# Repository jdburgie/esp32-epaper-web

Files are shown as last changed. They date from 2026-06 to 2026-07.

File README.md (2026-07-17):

# ESP32 E-Paper Web Display

Drive a 2.13" e-paper panel from an ESP32 (or an ESP8266/ESP-12E — see below)
and change the text from any browser on your network. No app, no cloud — just
type and submit.

## Enclosure & battery

A 3D-printable case and an 18650 + load-sharing-charger power design live in
[`enclosure/`](enclosure/) — parametric OpenSCAD source plus ready-to-print STLs,
a power BOM/wiring guide, and print/assembly notes.

## Hardware

- **MCU:** NodeMCU ESP32 DevKit V1 (30-pin) on a dual breakout/expansion shield
- **Driver board:** Inland e-paper driver board (SPI, 8-pin header, 5V/3.3V switch)
- **Panel:** FPC-A002 ribbon, 2.13" 250x122 b/w, SSD1680 controller

## Wiring

Driver board switch **P2 set to 3.3VIN**. All signal lines on the ESP32's
right-side header.

| Driver board | ESP32 pin | GPIO |
|---|---|---|
| SDI (MOSI) | D23 | 23 |
| SCLK (CLK) | D18 | 18 |
| CS | D5 | 5 |
| D/C | D19 | 19 |
| RES | RX2 | 16 |
| BUSY | D4 | 4 |
| VCC | 3V3 | — |
| GND | GND | — |

> Keep the board switch on **3.3VIN**. The logic lines are 3.3V — feeding the
> board 5V while driving 3.3V logic is the usual way these get fried.

## Libraries (Arduino IDE Library Manager)

- GxEPD2 (Jean-Marc Zingg)
- Adafruit GFX (dependency of GxEPD2)
- ESPAsyncWebServer (ESP32Async / me-no-dev)
- AsyncTCP (ESP32) — use **ESPAsyncTCP** instead if building for ESP8266 (see
  "ESP8266 (ESP-12E) port" below)

## Setup

**1. Wi-Fi credentials.** Create `secrets.h` next to the sketch (it's gitignored,
so it never gets committed and won't be in a fresh clone):

```cpp
#pragma once
#define SECRET_SSID "your-wifi-name"
#define SECRET_PASS "your-wifi-password"
#define OWM_API_KEY "your-openweathermap-key"   // for weather mode (openweathermap.org/api)

// Optional static IP (comment out USE_STATIC_IP for DHCP). Useful when the
// router has no DHCP reservation option and the station push needs a fixed
// target. Pick an address BELOW the router's DHCP pool to avoid collisions.
#define USE_STATIC_IP
#define STATIC_IP      192,168,12,50
#define STATIC_GATEWAY 192,168,12,1
#define STATIC_SUBNET  255,255,255,0
#define STATIC_DNS1    192,168,12,1
#define STATIC_DNS2    8,8,8,8
```

The sketch `#include`s this file and reads `SECRET_SSID` / `SECRET_PASS` /
`OWM_API_KEY` — you do **not** edit credentials in the `.ino` anymore. A free
OpenWeatherMap key works; if you don't need weather, any non-empty string is fine.

**2. Build & flash.** Either toolchain works:

- **PlatformIO** (config is in `platformio.ini`):
  ```
  pio run -t upload                       # build + flash
  pio device monitor -p COM3 -b 115200    # watch serial
  ```
  Set `upload_port` / `monitor_port` in `platformio.ini` to your board's COM port
  (it won't necessarily be COM3). Libraries resolve automatically.
- **Arduino IDE:** open `esp32-epaper-web.ino`, install the libraries listed above,
  select your ESP32 board + port, and upload.

**Over-the-air (OTA) updates.** After the first USB flash, the device runs
`ArduinoOTA` (hostname `epaper`, port 3232), so you can flash over Wi-Fi:
```
pio run -e esp32dev_ota -t upload        # uploads to upload_port (device IP) in platformio.ini
```
The partition scheme is `min_spiffs.csv` (two ~1.9 MB app slots) — OTA needs two
app partitions, so a USB flash with this scheme is required once before OTA works.
For a password, add `#define OTA_PASSWORD "…"` to `secrets.h` and set
`upload_flags = --auth=…` in the `esp32dev_ota` env.

**3. Use it.** Open the serial monitor at **115200** — it prints the device IP once
Wi-Fi connects. Browse to that IP. The current IP is also shown in the bottom-left
of the panel at all times.

**If Wi-Fi doesn't connect** (wrong password, network out of range, moved to a
new house), the device doesn't hang or go dark. After ~20s it starts a recovery
**access point** — the panel itself displays the AP name and its IP
(`192.168.4.1`). Connect a phone/laptop to that AP, browse to the IP, and use the
**Wi-Fi card** on the page to enter new credentials; the device saves them and
reboots to try again. This also means you can change Wi-Fi networks later without
re-flashing — the Wi-Fi card is always on the page, not just during recovery.

## Display modes

The control page (themed in the **Three Oak Woods** brand — palette, Nunito, and
the acorn badge served from `logo.h` at `/logo.svg`) offers these modes:

- **Clock** *(default view)* — NTP-synced date and time, redrawn every minute.
  Timezone is set by `TZ_INFO` in the sketch (default Mountain Time, auto DST).
- **Text** — type a message (multi-line supported) and hit **Update Display**.
- **Weather** — enter a US **ZIP code** and hit **Show Weather**. The panel shows
  a drawn weather icon, the **city**, a large **temperature**, the **condition**,
  and a **feels-like / humidity / wind** line. It **auto-refreshes every 5 min**.
- **Backyard Station** — live data pushed from a local **Ambient Weather** console
  (see below). Shows outdoor temp, humidity, wind + direction, gust, rain, and
  pressure, and **redraws on every push** while this mode is active. While waiting
  for the first push it shows a live counter, and **falls back to weather after
  ~90 s** so the panel never looks hung if the console isn't pushing yet.

The page also has a **Clean (de-ghost)** button that flashes the panel black↔white
to scrub e-paper ghosting; the same scrub runs automatically every 6 hours.

**Persistence:** the last view (and Wi-Fi credentials, if set via the recovery
AP) is saved to flash — NVS/`Preferences` on ESP32, a small LittleFS JSON file
on ESP8266 (same `prefs.getString/putString/...` call sites either way) — so
after a power loss the panel restores itself: a remembered ZIP boots straight
back to that weather view; otherwise it boots to the clock.

**Controls & extras:**
- **Physical button** (GPIO27 → GND) cycles Clock → Text → Weather → Station. Also
  on the page: **Next screen** and an **Auto-cycle** toggle.
- **Auto-cycle** advances the screen on a timer (~12 s), but **dwells longer (~30 s)
  on the text screen when it has notes**.
- **Text scrolling:** messages taller than 4 lines page through a 4-line window
  (with a `start/total` indicator).
- **Battery indicator:** an 18650 sensed on GPIO34 (via a 2:1 divider) shows a
  battery % in the top-right of every screen — auto-hidden when no cell is wired.
  See [`enclosure/`](enclosure/) for the battery + charger build.

Weather comes from **[OpenWeatherMap](https://openweathermap.org/api)** (current-
weather endpoint, `units=imperial`). Put a free API key in `secrets.h` as
`OWM_API_KEY`. The JSON response is parsed with ArduinoJson; the fetch uses HTTPS
with certificate validation disabled (fine for a home device). The weather icons
are drawn as 1-bit GFX primitives keyed off the OWM icon code (`01d`, `10n`, …) —
no bitmap assets needed.

> **Architecture note:** web handlers don't draw or fetch directly — they queue a
> `Pending` action that `loop()` executes. This keeps blocking SPI/TLS work off the
> AsyncTCP task and prevents two tasks touching the display at once.

### Connecting an Ambient Weather console (local push)

The ESP32 listens at **`/data/report/`** and ingests the console's "Customized"
upload — no cloud, no API key, your real backyard sensors every minute. In the
console's web UI (the *Customized* section):

| Field | Value |
|---|---|
| Customized | **Enable** |
| Protocol Type Same As | **AmbientWeather** |
| Server IP / Hostname | the **ESP32's IP** (give it a static IP / DHCP reservation so it stays put) |
| Path | `/data/report/` |
| Port | `80` |
| Upload Interval | `60` seconds |

The firmware parses `tempf`, `humidity`, `windspeedmph`, `windgustmph`, `winddir`,
`dailyrainin`, and `baromrelin` and replies `200 OK`. Your existing
AmbientWeather.net cloud upload is independent and keeps working. Tap **Show
Station** on the page to put the live feed on the panel.

> **AMBWeatherPro quirk:** this console joins its parameters onto the URL with
> `&` instead of `?` (`/data/report/&tempf=…`), so there's no query delimiter and
> a normal server parses nothing. The handler works around it by parsing the raw
> URL tail when no `?` is present — so no special path config is needed on the
> console; just set `Server` to the ESP's IP.

## ESP8266 (ESP-12E) port

The whole project also runs on an ESP8266 (e.g. a NodeMCU-style dev board with
an ESP-12E module) via the `esp12e` PlatformIO environment — same firmware,
same features (weather, station push, PWA, OTA, AP-mode recovery), split from
the ESP32 code by `#if defined(ESP32) / #elif defined(ESP8266)` throughout.

```
pio run -e esp12e -t upload           # first flash, over USB
pio run -e esp12e_ota -t upload       # later updates, over Wi-Fi (after the first USB flash)
```

**Wiring (NodeMCU D-pin → GPIO).** Hardware SPI is fixed (SCK/MOSI below) and
used automatically — don't wire anything to D6. **D8/GPIO15 is intentionally
unused**: it must read LOW at boot, and an e-paper driver board's CS-idle
pull-up on that line can prevent the ESP8266 from booting at all.

| Driver board | NodeMCU pin | GPIO | Why this pin |
|---|---|---|---|
| SDI (MOSI) | D7 | 13 | fixed HW SPI |
| SCLK (CLK) | D5 | 14 | fixed HW SPI |
| CS | D3 | 0 | output only — safe on a boot-strap pin |
| D/C | D4 | 2 | output only (also drives the onboard LED — cosmetic) |
| RES | D0 | 16 | no boot-strap meaning either way |
| BUSY | D2 | 4 | **input** from the display — needs a pin with no boot meaning |
| Button | D1 | 5 | input w/ pullup — same reasoning as BUSY |
| Battery | A0 | — | the only ADC pin |
| VCC / GND | 3V3 / GND | — | |

**Battery sense needs empirical calibration.** ESP8266 has one 0–1V ADC; a
NodeMCU board's onboard divider ratio varies by vendor/clone, and this project
adds its **own** 100k/100k divider on top (same physical design as the ESP32
board, feeding A0 at roughly half the cell voltage — safe under any onboard
divider variant). The combined ratio isn't knowable in advance: connect a
charged cell through the divider, compare a multimeter reading to
`analogRead(A0)` in `/status.json`'s `battRawMv`, and set
`BATT_ESP8266_FULLSCALE_V` in the sketch to `(multimeter volts) / (raw/1023.0)`.

**Libraries differ from the ESP32 build:** `ESPAsyncTCP` instead of `AsyncTCP`,
`LittleFS` instead of `Preferences`, `ESP8266WiFi`/`ESP8266HTTPClient` instead
of `WiFi`/`HTTPClient` — all handled by the `esp12e` env's `lib_deps` and the
sketch's `#ifdef`s; nothing to configure by hand.

**PROGMEM matters here.** The embedded web app, logo, and PWA icon are ~14 KB +
12 KB + 23 KB constant blobs. ESP8266 only has ~80 KB of RAM total, and without
`PROGMEM` (keeping them in flash instead of copying to RAM) the firmware simply
won't link. If you regenerate `webapp.h` after editing the web app, keep the
`PROGMEM` keyword — see `webapp/README.md`.

**Static IP: this board is now the deployed device.** `secrets.h`'s
`USE_STATIC_IP` block used to be guarded to `#if defined(ESP32)` specifically so
an ESP8266 build could never collide with the ESP32 unit's static `.50`. That
guard was removed once the ESP32 unit was retired — **this ESP8266/ESP-12E
board now holds `.50`** (see JOURNAL.md). If you ever bring the old ESP32 board
back online while building from this same `secrets.h`, it will *also* try to
claim `.50` and collide with this one — give it a different address (or a
different `secrets.h`) first.

> **Verified so far:** boot, Wi-Fi connect, the recovery AP fallback (forced by
> pointing it at a nonexistent network), the web server/PWA/persistence (all
> stable over USB and OTA flashes) — all on a board with **no e-paper panel
> physically attached yet**. The wiring table above is the intended pin map,
> not yet confirmed against a real panel; the pin choices *do* specifically
> avoid the known ESP8266 boot-strap traps (see the "why this pin" column), but
> give the display module itself a first test before trusting it blind.

## Panel / constructor notes

`FPC-A002` is the *cable* part number, not the controller, and a few revisions
have shipped on that same ribbon. The sketch uses `GxEPD2_213_BN` (SSD1680),
the most common match. If the screen comes up blank or garbled, swap that one
constructor line and re-flash, in this order:

1. `GxEPD2_213_BN`  (default — SSD1680)
2. `GxEPD2_213_B74` (SSD1680, newer revision)
3. `GxEPD2_213_B73` (SSD1675-based)
4. `GxEPD2_213_B72` (SSD1675-based)

The canonical list of every constructor lives in
**File → Examples → GxEPD2 → GxEPD2_Example**.

## Known tradeoffs

- **No deep sleep.** A web server needs the chip awake and on Wi-Fi, so this
  trades microamp sleep current for being interactive. The *panel* still
  hibernates between updates, so burn-in protection is intact.
- **Full-window refresh** every update (the black/white flash). Safe default,
  prevents ghosting. Partial updates are possible later for snappier redraws.
- **No auth or input sanitizing.** Fine on a trusted home network; don't expose
  it to the internet as-is. HTML special characters (`<`, `&`) render literally
  on the panel but can break the web page's "currently showing" line.

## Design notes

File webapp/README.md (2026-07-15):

# Web app (PWA)

A web app that controls the e-paper display from any phone or laptop — a richer
alternative to the minimal page the device serves itself. It talks to the
device's HTTP API and polls `/status.json` for live state (mode, battery,
weather, station). It's a **PWA**: add it to your home screen and it runs
full-screen/standalone with the Three Oak Woods icon.

## Install (add to home screen)
Open the app on the device (`http://192.168.12.50/app`), then:
- **Android (Chrome):** ⋮ menu → **Add to Home screen** (or the **Install app**
  button if it appears).
- **iOS (Safari):** Share → **Add to Home Screen**.

It installs with the badge icon and opens chrome-less, talking to the device
over your LAN.

> **Why no offline / no auto-install prompt:** service workers (offline caching
> and the one-tap install prompt) require a **secure context** — HTTPS or
> localhost. The device serves plain **HTTP**, so the service worker doesn't
> register there (the app still installs to the home screen and works; it just
> isn't cached offline). Hosting the app on HTTPS *would* enable offline, but
> then the browser blocks it from reading the HTTP device (mixed content). Since
> live device data is the whole point, **HTTP-from-the-device is the right call**
> here. The service worker is included and self-activates **if** you ever serve
> the app from a secure origin.

## Run it
**Easiest — the device serves it.** The firmware bundles this app and serves it at
**`/app`**, and the device's control page has an **"Open the web app ↗"** link.
Just browse to the device (e.g. `http://192.168.12.50/`) and click it — no
hosting, and it auto-targets the device it's served from (same origin, no CORS).

**Standalone** — you can also open [`index.html`](index.html) directly (double-click,
`python -m http.server`, or GitHub Pages), then enter the device address and hit
**Connect** (saved in `localStorage`). Cross-origin reads work because the firmware
sends `Access-Control-Allow-Origin: *`.

> **Regenerating the bundle:** the device serves `webapp.h` (auto-generated from
> `index.html`). After editing the SPA, regenerate it from the repo root:
> ```
> { printf '#pragma once\nconst char WEBAPP_HTML[] PROGMEM = R"WEBAPP(\n'; cat webapp/index.html; printf '\n)WEBAPP";\n'; } > webapp.h
> ```
> (prepend the two `// Auto-generated` comment lines if you like), then reflash.
> **Keep the `PROGMEM` keyword** — this ~14KB blob overflows the ESP8266 port's
> RAM without it (harmless/no-op on ESP32). The device reads it via `send_P`,
> which is PROGMEM-aware.

## What it does
- **Live status** every 5 s from `/status.json`: current screen, battery %/volts,
  auto-cycle state.
- **Weather view:** OpenWeatherMap conditions — emoji icon, big temp, city,
  description, and feels-like / humidity / wind.
- **Backyard station view:** live console data — temp, humidity, wind + compass
  direction, gust, rain today, and pressure.
- **Controls** (call the device's existing endpoints):
  - Screens: Clock, Station, Weather (with ZIP), Next, Auto-cycle toggle.
  - Text: multi-line note → Update display.
  - Clear, Clean (de-ghost).

## Why CORS
The app is served from a *different origin* than the device (a file or a host,
not the ESP itself), so the browser blocks reading the device's responses unless
the device sends `Access-Control-Allow-Origin`. The branch firmware adds that
header globally; the action endpoints are simple GETs (no preflight needed).

## Notes
- All control endpoints are plain GET and the app fires them with
  `redirect:'manual'` so it doesn't drag down the device's HTML on every tap.
- The device logo is loaded live from `http://<device>/logo.svg`.
- No build step, no dependencies — one HTML file (Nunito is loaded from Google
  Fonts; it falls back to a system sans if offline).

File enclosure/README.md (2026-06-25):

# Enclosure + battery — ESP32 e-paper weather display

A two-part 3D-printed case that houses the ESP32, the 2.13" e-paper module, an
18650 cell, and a **load-sharing** charger so the unit runs on battery and
recharges over USB *while still running*.

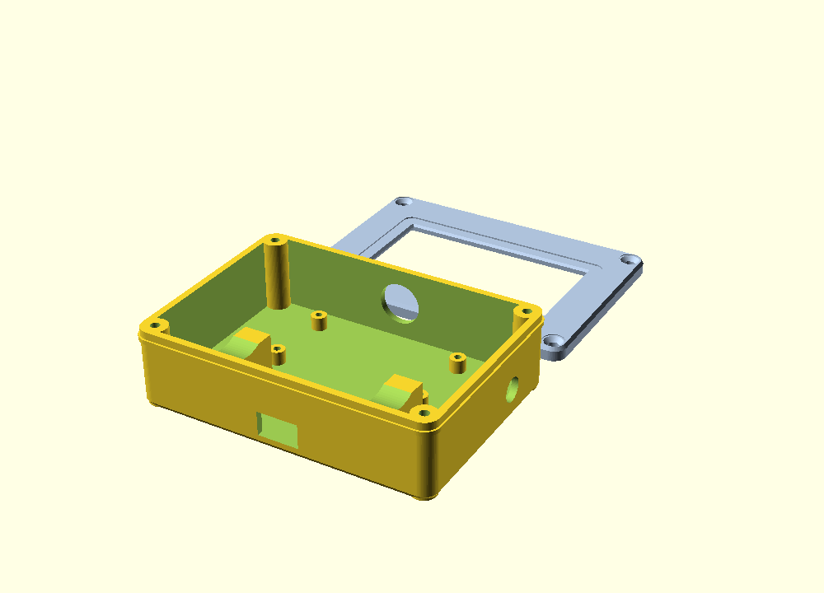
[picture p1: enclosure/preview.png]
preview


Files:
- [`epaper-case.scad`](epaper-case.scad) — parametric source (edit the dims to fit your parts)
- `epaper-case-shell.stl` — the body (electronics + battery)
- `epaper-case-front.stl` — the front plate / display bezel
- `epaper-case-stand.stl` — desk easel/kickstand (the case slots in, tilted back)

---

## Power: 18650 + load-sharing charger

> ⚠️ **Why not a bare TP4056?** A plain TP4056 module is *not* load-sharing —
> running the ESP32 off the cell while the TP4056 charges it confuses the charge
> termination and stresses the battery. Use a module with real load sharing /
> power-path (below).

**Recommended — Adafruit PowerBoost 1000C** (cleanest): a LiPo/Li-ion charger +
5 V boost with **true load sharing** — you can power the load while it charges.

**Budget — IP5306 power-bank module** (~$3, includes an 18650 holder): charges
over USB and outputs a boosted 5 V with pass-through. It auto-shuts-off below
~45 mA, but the ESP32 with Wi-Fi active draws well above that, so it stays on.

### Bill of materials
| Qty | Part |
|----|---|
| 1 | ESP32 DevKit V1 (already have) |
| 1 | 2.13" SSD1680 e-paper module (already have) |
| 1 | **Load-sharing charger** — Adafruit PowerBoost 1000C *or* IP5306 module |
| 1 | 18650 cell, protected, 2500–3500 mAh |
| 1 | 18650 holder (if not on the charger module) |
| 1 | SPST slide/rocker switch (optional, fits the side hole) |
| 4 | M2.5 × 8 mm self-tapping screws (corners) |
| — | Hookup wire, heat-shrink |

### Wiring
```
  18650 (+) ──► BAT+ ┐
  18650 (−) ──► BAT− ┤  [ load-sharing charger ]   USB ◄── charge here
                     │
                  5V OUT ──► ESP32  VIN     (5 V pin)
                  GND    ──► ESP32  GND
```

### Cycle button + battery sense (optional firmware features)
```
  Button:   ESP32 GPIO27 ──[ momentary button ]── GND     (internal pull-up; tap = next screen)

  Battery:  18650 (+) ──[ 100k ]──┬──► ESP32 GPIO34
                                  [ 100k ]
                                    │
                                   GND
```
- **Button** mounts in the case's **top hole** (`btn_d`). A short press cycles
  Clock → Text → Weather → Station. (GPIO27 is configured `INPUT_PULLUP`.)
- **Battery sense**: the 100k/100k divider halves the cell voltage into GPIO34
  (an input-only ADC pin). The firmware auto-detects it — the battery % overlay
  appears only when a plausible voltage is present, so it's safe to leave
  unwired. Tune `BATT_RATIO` in the sketch if you use different resistors.
- Charge through the **charger module's** USB port (routed to the case's bottom
  slot) — *not* the ESP32's USB.
- Optional: put the SPST switch in the **5 V OUT** line (or the module's EN pin)
  and mount it in the side hole.
- The firmware needs no changes — it just sees 5 V on VIN like before.

### Runtime
A ~3000 mAh cell at ~100–150 mA average (ESP32 + Wi-Fi is the main draw; the
e-paper only sips during refreshes), through a boost converter at ~85%, gives
roughly **12–18 hours** per charge. The always-on web server prevents deep
sleep, so that's the trade-off for being instantly reachable. Want days instead
of hours? That needs a deep-sleep architecture (and giving up the live server).

> Li-ion safety: use a **protected** cell or a module with DW01 protection, never
> short the terminals, charge only via the module's USB, and watch the first
> charge.

---

## Mounting

- **Desk easel (kickstand):** print `epaper-case-stand.stl` (or `part="stand"`).
  The assembled case drops into the channel and leans back `stand_tilt`° (15° default).
- **Wall mount:** set `wall_mount = true` to add two keyhole slots in the back
  wall, then re-render the shell. ⚠️ The screw heads sit *inside* the cavity, so
  move `km_y` clear of the battery/ESP — or just use the easel.

## Printing

| Setting | Value |
|---|---|
| Material | PLA or PETG |
| Layer height | 0.2 mm |
| Walls / perimeters | 3 |
| Infill | 20% |
| Supports | **None needed** — print each part flat (open side up) |
| Orientation | shell: cavity up · front: visible face down on the bed |

Both parts print without supports. The corner countersinks on the front plate
come out cleanest with the bezel face on the build plate.

### Re-render the STLs after editing
```
openscad -D 'part="shell"' -o epaper-case-shell.stl epaper-case.scad
openscad -D 'part="front"' -o epaper-case-front.stl epaper-case.scad
```

---

## Assembly
1. **Measure & re-fit:** the `.scad` defaults are typical, not exact. Measure your
   display module, ESP32, holder, and charger, update the variables at the top of
   `epaper-case.scad`, and re-render. `tol` (0.4 mm) tunes press-fit snugness.
2. Seat the **e-paper module** face-down into the front plate's pocket (the
   window lip retains it).
3. Mount the **ESP32** on the four standoffs (self-tap M2 or a dab of hot glue).
4. Drop the **18650 holder/charger** onto the cradle saddles; route the USB port
   to the bottom slot and the optional switch to the side hole.
5. Wire per the diagram, tuck the ribbon/wires, and screw the **front plate** to
   the four corner posts with M2.5 × 8 mm screws.

---

## Customizing `epaper-case.scad`
Every dimension is a labeled variable at the top (display, ESP32, 18650, charger,
ports, screws). Common tweaks:
- `tol` — looser/tighter fits.
- `win_w` / `win_h` / `win_dx` / `win_dy` — match & position the visible window to
  your panel's active area.
- `sw_d = 0` — omit the switch hole.
- `batt_l` / `cell_d` — match your holder and cell.
- `wall`, `fillet` — wall thickness and corner softness.

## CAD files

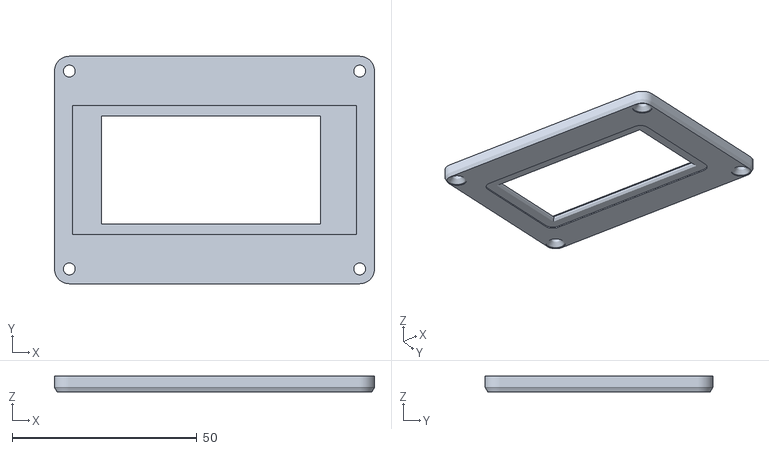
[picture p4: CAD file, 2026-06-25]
enclosure/epaper-case-front.stl
86.5 x 61.5 x 4.20

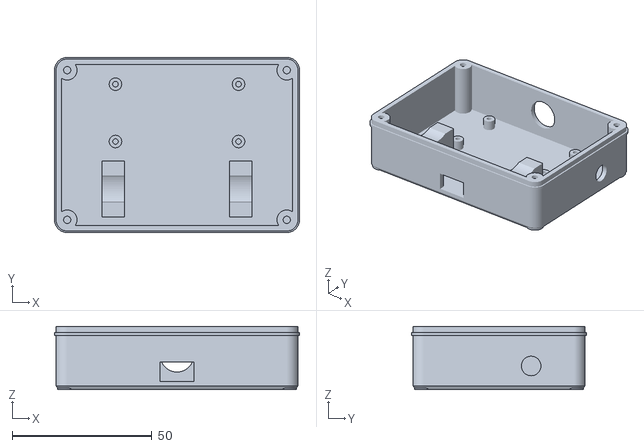
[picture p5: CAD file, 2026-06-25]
enclosure/epaper-case-shell.stl
87.6 x 62.6 x 22.7

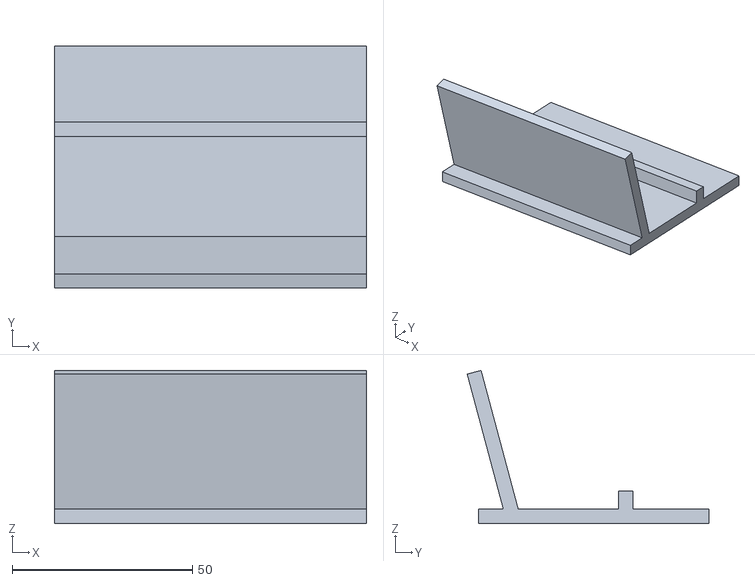
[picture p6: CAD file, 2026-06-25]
enclosure/epaper-case-stand.stl
86.5 x 67.0 x 42.5

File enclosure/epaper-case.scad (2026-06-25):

// ============================================================================
//  ESP32 e-paper weather display — refined parametric enclosure
//  Three Oak Woods · esp32-epaper-web
//
//  This edition preserves the original INTERNAL cavity, component locations,
//  port locations, standoffs, battery cradle, screw centres, and display pocket.
//  Only the exterior treatment has been redesigned.
//
//  New exterior treatment:
//    • softly beveled rear shell edge
//    • subtle wraparound accent band near the front seam
//    • tapered/chamfered faceplate perimeter
//    • shallow recessed display panel
//    • beveled display-window opening
//    • softened countersink surrounds
//
//  Units: millimetres.
// ============================================================================

part = "all";          // "all" | "shell" | "front"

/* [Global] */
wall   = 2.0;          // wall / floor thickness
// NOTE: cavity dimensions and all internal geometry remain based on this value.
tol    = 0.4;          // clearance for press-fits
fillet = 3.0;          // legacy/internal corner-radius basis
eps    = 0.1;          // tiny overlap to avoid coincident faces
$fn    = 72;

/* [Exterior styling] */
body_radius       = 4.0;   // larger, softer external corner radius
rear_bevel        = 1.4;   // depth of bevel around rear shell face
rear_inset        = 1.0;   // amount rear face steps inward on each side
accent_enable     = true;  // subtle wraparound band on shell
accent_outset     = 0.55;  // projection of accent band per side
accent_height     = 1.15;  // Z height of accent band
accent_from_front = 2.2;   // distance behind shell/front seam
front_chamfer     = 1.15;  // faceplate perimeter chamfer depth
front_inset       = 0.65;  // visible face inset per side
panel_recess      = 0.45;  // shallow display-surround recess
panel_margin_x    = 4.2;   // recess margin around visible window
panel_margin_y    = 4.0;
panel_radius      = 3.0;
window_bevel      = 0.75;  // bevel width around display opening
window_bevel_z    = 0.70;  // bevel depth
screw_dish_extra  = 0.5;   // soft circular relief around each countersink
screw_dish_depth  = 0.28;

/* [E-paper display module] */
disp_w  = 76.5;        // module outline width  (X)
disp_h  = 34.5;        // module outline height (Y)
disp_t  = 2.4;         // module thickness seated in the front pocket
win_w   = 59.2;        // visible active-area window width
win_h   = 29.3;        // visible active-area window height
win_dx  = -1.0;         // window offset from module centre (X)
win_dy  = 0.0;         // window offset from module centre (Y)
win_lip = 1.8;         // faceplate thickness around the window (retains module)

/* [ESP32 DevKit V1 (30-pin)] */
esp_l        = 52.0;   // PCB length (X)
esp_w        = 28.5;   // PCB width  (Y)
esp_h        = 13.0;   // height incl. headers (Z clearance)
esp_standoff = 4.0;   // standoff post height under the PCB
esp_post_d   = 4.5;    // standoff post diameter
esp_pin_d    = 2.0;    // self-tap pilot in the post

/* [18650 holder] */
batt_l  = 76.0;        // holder length incl. terminals (X)
batt_w  = 20.0;        // holder width (Y)
cell_d  = 18.7;        // bare cell diameter (for the cradle saddles)

/* [Charger module: IP5306 board or Adafruit PowerBoost 1000C] */
chg_l   = 40.0;        // board length
chg_w   = 25.0;        // board width

/* [Ports] */
usb_w   = 12.0;        // charge-port cutout width  (bottom wall)
usb_h   = 7.0;         // charge-port cutout height
sw_d    = 7.0;         // power-switch hole dia on a side wall (0 = omit)
btn_d   = 12.0;        // cycle-button hole dia on the TOP wall (0 = omit)

/* [Mounting] */
wall_mount = false;    // true = add 2 keyhole slots in the back wall
km_dx      = 28.0;     // keyhole spacing from centre (X)
km_y       = 0.0;      // keyhole height offset (Y) — nudge clear of components
stand_tilt = 15;       // easel lean-back angle for the `stand` part

/* [Corner screws] */
scr_d      = 2.6;      // self-tap shaft into the posts (M2.5/M3 self-tapping)
scr_clear  = 3.2;      // clearance hole through the front plate
scr_head   = 6.0;      // countersink dia
post_d     = 7.0;      // corner post diameter

// ---------------------------------------------------------------------------
//  Derived cavity / outer dimensions — unchanged from the original design
// ---------------------------------------------------------------------------
margin  = 3.0;
inner_x = max(batt_l, esp_l, disp_w, chg_l) + 2*margin;
inner_y = batt_w + esp_w + 3*margin;
inner_z = max(cell_d, esp_h) + 2;

out_x   = inner_x + 2*wall;
out_y   = inner_y + 2*wall;
shell_z = inner_z + wall;
front_t = win_lip + disp_t;

batt_cy = -inner_y/2 + batt_w/2 + margin;
esp_cy  =  inner_y/2 - esp_w/2  - margin;

px = inner_x/2 - 2;
py = inner_y/2 - 2;

// ---------------------------------------------------------------------------
//  Helpers
// ---------------------------------------------------------------------------
module rr2d(x, y, r) {
  // Rounded rectangle with predictable outside dimensions.
  offset(r) offset(-r) square([x, y], center=true);
}

module rbox(x, y, z, r) {
  linear_extrude(z) rr2d(x, y, r);
}

module hull_slice(x, y, r, z, h=0.12) {
  translate([0,0,z]) linear_extrude(h) rr2d(x, y, r);
}

// Shell exterior: smaller back face flows into the full mating footprint.
module sculpted_shell_outer() {
  union() {
    hull() {
      hull_slice(out_x - 2*rear_inset,
                 out_y - 2*rear_inset,
                 max(1.0, body_radius - rear_inset),
                 0);
      hull_slice(out_x, out_y, body_radius, rear_bevel);
    }
    translate([0,0,rear_bevel])
      rbox(out_x, out_y, shell_z - rear_bevel, body_radius);
  }
}

// Faceplate exterior: exact mating footprint on the inside, gently inset face.
module sculpted_front_outer() {
  union() {
    hull() {
      hull_slice(out_x - 2*front_inset,
                 out_y - 2*front_inset,
                 max(1.0, body_radius - front_inset),
                 0);
      hull_slice(out_x, out_y, body_radius, front_chamfer);
    }
    translate([0,0,front_chamfer])
      rbox(out_x, out_y, front_t - front_chamfer, body_radius);
  }
}

module accent_ring() {
  ring_z = shell_z - accent_from_front - accent_height;
  difference() {
    translate([0,0,ring_z])
      rbox(out_x + 2*accent_outset,
           out_y + 2*accent_outset,
           accent_height,
           body_radius + accent_outset);
    // Preserve the original cavity exactly.
    translate([0,0,ring_z-eps])
      rbox(inner_x, inner_y, accent_height + 2*eps,
           max(0.1, fillet-wall));
  }
}

module beveled_window_cut() {
  // Larger at the visible face, tapering to the exact original opening.
  translate([win_dx, win_dy, panel_recess-eps])
    linear_extrude(height=window_bevel_z + eps,
                   scale=[win_w/(win_w + 2*window_bevel),
                          win_h/(win_h + 2*window_bevel)])
      square([win_w + 2*window_bevel,
              win_h + 2*window_bevel], center=true);

  // Exact original visible-window dimensions through the remaining plate.
  translate([win_dx, win_dy, panel_recess + window_bevel_z-eps])
    linear_extrude(front_t + 2)
      square([win_w, win_h], center=true);
}

module display_panel_recess() {
  translate([win_dx, win_dy, -eps])
    linear_extrude(panel_recess + eps)
      rr2d(win_w + 2*panel_margin_x,
           win_h + 2*panel_margin_y,
           panel_radius);
}

module screw_face_relief() {
  for (sx=[-1,1], sy=[-1,1])
    translate([sx*px, sy*py, -eps])
      cylinder(d=scr_head + screw_dish_extra,
               h=screw_dish_depth + eps);
}

// Wall-mount keyhole: head hole + a slot the screw shank slides up into.
// Cut through the back wall. Head sits inside the cavity — keep km_y clear
// of the battery/ESP, or just use the `stand` part.
module keyhole() {
  union() {
    cylinder(d=8, h=wall*3, center=true);                               // head
    hull() { cylinder(d=4, h=wall*3, center=true);
             translate([0,8,0]) cylinder(d=4, h=wall*3, center=true); } // shank slot
  }
}

// Desk easel: the assembled case drops into a channel and leans back stand_tilt deg.
module stand() {
  case_z = shell_z + front_t;           // assembled depth held by the channel
  d      = stand_tilt + case_z + 22;    // foot depth on the desk
  rest_h = case_z + 16;
  lip_y  = 8 + case_z + 4;
  translate([-out_x/2, -d/2, 0]) {
    cube([out_x, d, wall*2]);                                  // foot
    translate([0, lip_y, 0]) cube([out_x, wall*2, 9]);         // front lip
    translate([0, 8, 0]) rotate([stand_tilt,0,0])              // angled back rest
      cube([out_x, wall*2, rest_h]);
  }
}
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

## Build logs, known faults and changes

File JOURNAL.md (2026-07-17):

# Project Journal

A running log of work on the ESP32 e-paper web display, so the project can be
picked up from any machine. Newest entries at the top. Hardware, wiring, and
usage live in [README.md](README.md); this file tracks **state, decisions, and
history**.

---

## 2026-07-15 — ESP8266 board takes over `.50` (ESP32 unit retired)
User took the ESP32 unit at `.50` down and designated the ESP8266/ESP-12E board
(previously DHCP at `192.168.12.206`) as its replacement — **on purpose**, not
a mistake to catch. This directly reverses a deliberate safety guard from the
ESP8266 port work: `secrets.h`'s `USE_STATIC_IP` block was `#if defined(ESP32)`-
only specifically so the ESP8266 board could never accidentally collide with
the ESP32 unit's `.50`. With the ESP32 unit actually gone, that guard no longer
served its purpose, so:

- **`esp32-epaper-web.ino`:** static-IP guard widened from
  `#if defined(ESP32) && defined(USE_STATIC_IP)` to `#if defined(USE_STATIC_IP)`
  — both platforms now honor it. (Verified `ESP8266WiFi.h`'s `WiFi` object has
  the same `.mode()`/`.config(ip,gw,subnet,dns1,dns2)` signature as ESP32's, so
  no other code changes were needed.)
- **`platformio.ini`:** `esp12e_ota` `upload_port` → `192.168.12.50` (was the
  DHCP `.206`). `esp32dev_ota` `upload_port` defused to a placeholder
  (`CHANGE_ME_ESP32_DEVICE_IP`) — it used to point at `.50`, which is now the
  ESP8266 board; OTA has no architecture check, so blindly firing an
  ESP32-compiled binary at `.50` over espota would very likely **brick the
  ESP8266 board** (incompatible flash layout/bootloader). Left as a deliberate
  landmine defusal, not just a stale value.
- **README:** the "Static IP is ESP32-only, on purpose" section rewritten to
  reflect the new reality and warn about bringing the old ESP32 board back
  online with the same `secrets.h` (it would also try to claim `.50`).
- Built `esp12e` clean, flashed via **OTA to `.206`** (its address *before* this
  change took effect), and verified after reboot: `status.json` now reports
  `"ip":"192.168.12.50"`, `.206` no longer responds, backyard station data
  flowing (88°F, live push). Battery still reads invalid on this board — sense
  divider not wired/calibrated yet (see README's ESP8266 battery-calibration
  note).

---

## 2026-07-02 — ESP8266/ESP-12E port + Wi-Fi AP-mode recovery (both platforms)
User attached an ESP8266EX (NodeMCU-style dev board, CP210x on COM3, 4MB flash,
MAC `e0:98:06:a7:a4:0c`) and asked to (a) port the project to it and (b) add an
AP-mode fallback when Wi-Fi can't connect. Did both; verified on real hardware
(no panel wired yet — logic/network/persistence only).

**AP-mode recovery (works on BOTH ESP32 and ESP8266, one shared code path):**
- `connectWiFi(ssid, pass, timeoutMs)` replaces the old infinite
  `while(!connected) delay()` loop — bounded (20s), so a bad/absent network
  can't hang the device forever.
- Boot now tries **stored** creds (from a prior `/wifisave`, in
  Preferences/LittleFS) first, then the compiled `secrets.h` defaults.
- If both fail: `startApFallback()` starts an open AP named
  `EPaper-Setup-<MAC suffix>`, IP `192.168.4.1`, and **draws the AP name + IP
  directly on the e-paper panel** (`drawApSetup()`) — recovery instructions are
  visible without a serial monitor or router lookup.
- New **Wi-Fi card** on the control page (always present, not just during
  recovery) posts to `/wifisave`, which persists the new SSID/pass and
  `ESP.restart()`s. Lets you change networks later without re-flashing.
- **Verified live:** forced failure by temporarily pointing `secrets.h` at a
  nonexistent SSID, reflashed — serial confirmed the bounded timeout, correct
  AP name/IP, a clean single draw cycle (no reset-loop), and OTA still
  starting in AP mode. Restored real creds after.

**ESP8266 (ESP-12E) port — one shared `.ino`, `#if defined(ESP32)/#elif ESP8266`:**
- New `[env:esp12e]` (`platform=espressif8266`, `board=nodemcuv2`) +
  `[env:esp12e_ota]` in `platformio.ini`.
- **Pin map redesigned for ESP8266's boot-strap constraints** (documented in
  README): CS=D3/GPIO0, DC=D4/GPIO2 (outputs we drive, safe on boot pins),
  RST=D0/GPIO16, BUSY=D2/GPIO4, Button=D1/GPIO5 (inputs — placed on pins with
  no boot-strap meaning, since we don't control what those lines read at
  power-on). **D8/GPIO15 deliberately avoided** — must be LOW at boot, and an
  e-paper CS-idle pull-up there can brick the boot.
- **Persistence:** `Preferences` has no ESP8266 equivalent → wrote `FilePrefs`,
  a drop-in shim (same `getString/putString/getInt/...` surface) backed by one
  JSON file on LittleFS. Every existing `prefs.*` call site works unchanged.
- **Battery:** `analogReadMilliVolts()` is ESP32-only. ESP8266 has one 0-1V ADC;
  kept the same external 100k/100k divider design (safe regardless of a
  NodeMCU clone's unknown onboard divider) but the combined ratio needs
  **empirical calibration** (`BATT_ESP8266_FULLSCALE_V`, documented in README)
  — no formula can predict an unknown board's onboard divider.
- **Libraries:** `ESPAsyncTCP` (not `AsyncTCP`), `LittleFS`, `ESP8266WiFi`/
  `ESP8266HTTPClient`. `HTTPClient::setConnectTimeout()` doesn't exist on
  ESP8266 — guarded `#if defined(ESP32)`.
- **The big gotcha — RAM overflow at LINK time:** first ESP8266 build failed
  (`.bss` doesn't fit in `dram0_0_seg`). `nm --size-sort` on the object file
  showed why: `webapp_icon_192_png` (23KB), `WEBAPP_HTML` (13.5KB), and
  `THREEOAKWOODS_BADGE_SVG` (11.8KB) — const blobs that ESP32 happily
  flash-maps by default, ESP8266 does NOT without an explicit `PROGMEM`
  attribute (ESP8266 has no unified flash/RAM address space the way ESP32
  does). Added `PROGMEM` to all four large const declarations (icon.h, logo.h,
  webapp.h, DEVICE_MANIFEST/DEVICE_SW) and switched their route handlers to
  `send_P`/`beginResponse_P`. Fixed: RAM dropped to 54% with headroom.
  **webapp/README.md's regen command updated to keep `PROGMEM`** — a plain
  regen would silently reintroduce the overflow.
- **Verified live (COM3, IP `192.168.12.206`):** clean boot + STA connect to
  the real network, stable across 5 consecutive requests, `/app` (PWA) and
  `/logo.svg` byte-for-byte intact (not garbled by the PROGMEM switch),
  `/set` + LittleFS persistence survives a real reboot, and a full OTA flash
  (`esp12e_ota`) succeeded and came back up stable.
- ESP32 build re-verified unaffected by all of the above (PROGMEM is a no-op
  there; it was already using `beginResponse_P` for the icon).
- **Not yet tested:** the e-paper panel isn't physically wired to this board —
  everything above is network/logic/persistence verification only. Pin map is
  designed to avoid known boot traps but unconfirmed against a real display.

---

## 2026-07-02 — Web app: "Show all data" for the backyard station
Previously the firmware only kept 7 fields from the Ambient console's push
(temp/humidity/wind/gust/rain-today/pressure/wind-dir) — everything else the
console sends was parsed into `/debug` logs but discarded. Expanded the
`Station` struct + `onReport` parsing to keep **all ~26 fields**: 10-min avg
wind speed/direction, max daily gust, UV index, solar radiation, all six rain
intervals (hourly/event/daily/weekly/monthly/yearly), absolute + relative
pressure, indoor temp/humidity, sensor battery flags, lightning strikes today,
station type, and the UTC observation timestamp. All exposed via `/status.json`.

Web app gained a **"Show all data ▾"** toggle under the Backyard Station card —
expands a grouped table (Outdoor / Rain / Pressure / Indoor / Sensors) with
friendly labels + units for every field the console actually reported (fields
not sent by a given station just don't show a row). Curated summary cards and
the physical panel view are unchanged — this is purely additive.

Flashed via **OTA** (no cable). Verified live: full 26-field payload in
`/status.json`, toggle present in the served `/app` page.

---

## 2026-07-01 — Third board discovered on COM9; flashed with e-paper firmware
A board plugged into **COM9** (Silicon Labs CP210x) turned out to be **yet
another** physical ESP32 — MAC `24:0a:c4:12:87:b4` (distinct from the deployed
unit `24:0a:c4:12:88:18` at `.50`). It was running unknown custom firmware,
stuck trying to join a Wi-Fi network called **"Three Oak Wood2"** (not the real
"Three Oak Wood" network) — never verified against any known project in memory.

Per user direction, flashed it with the e-paper project so it joins the correct
network. **Static IP had to be temporarily disabled** for this flash (`secrets.h`
`USE_STATIC_IP` briefly commented out) — the default `192.168.12.50` is already
claimed by the deployed board, and flashing both with the same static IP would
have caused a conflict. `secrets.h` was restored to its normal static-IP state
immediately after. This board is now on **DHCP** at `192.168.12.216`, OTA-ready
(`epaper.local` / `192.168.12.216:3232`), verified via HTTP (`mode:"clock"`).

**Same "no panel" signature as before** (`_Update_Full : 1`) — expected, this is
presumably a bare dev board with no e-paper module wired yet.

⚠️ **mDNS hostname collision:** both this board and the deployed `.50` unit
advertise OTA under the same hostname `"epaper"` — `epaper.local` will be
ambiguous with two boards live. Give this board a distinct `ArduinoOTA.setHostname()`
if it stays on the network long-term (not yet done).

**Resolved same session:** user confirmed this board **replaces `.50`** ("just
playing around"). Re-flashed with static IP restored — now live at
**`192.168.12.50`**, confirmed via ARP (`24-0a-c4-12-87-b4` answering at `.50`,
no conflict). The old deployed unit (`24:0a:c4:12:88:18`) is retired/superseded;
if it's ever powered on the same network again it'll IP-conflict with this one —
unplug it or give it a different address if kept around. OTA hostname collision
note above no longer applies unless the old board comes back online.

---

## 2026-06-26 — board reflashed as the sprinkler by mistake; ✅ RESTORED on a new board

The deployed e-paper board (ESP32-D0WD-V3 on a DOIT DevKit, MAC `08:b6:1f:f0:01:64`,
static IP `192.168.12.50`) was mistaken for a spare and **reflashed with the
`esp32-sprinkler-controller` firmware** — it now runs the sprinkler at `192.168.12.51`.
The e-paper firmware was overwritten (nothing physically damaged). Caught via ARP:
`.50` → that MAC, and `.50` no longer answers HTTP.

Recovery prep (done this session): re-cloned the repo, recreated `secrets.h` (Wi-Fi creds;
`OWM_API_KEY` left blank pending the key), and `pio run` builds clean (35% of the 3 MB
`huge_app` partition).

**To restore:** a 30-pin ESP32 DevKit V1 + the Inland 2.13" panel, then
`pio run -e esp32dev -t upload`. Open decision: re-use the original board (and move the
sprinkler onto a different ESP32) vs. rebuild the e-paper on a second board. Need the
OpenWeatherMap key for weather mode (clock/text/station work without it).

**RESOLVED same day:** flashed the e-paper firmware onto a fresh spare ESP32 — an
**ESP32-D0WDQ6, MAC `24:0a:c4:12:88:18`** (it had only the stock "Hello from ESP32!"
demo on it; verified first this time). Boots clean, serves the "Three Oak Woods Display"
control page, and pinned back to **static `192.168.12.50`** (added the `USE_STATIC_IP`
block to `secrets.h`). Sprinkler left untouched on its own board (`.51`). **Still TODO:**
wire the Inland 2.13" panel to this board (`MOSI→23, SCLK→18, CS→5, DC→19, RES→16,
BUSY→4, VCC→3V3, GND→GND`, P2→3.3VIN) so the display physically draws, and add the OWM
key for weather mode.

---

## Working from another computer (bootstrap)

1. **Clone the repo** and open the folder.
2. **Recreate `secrets.h`** — it's gitignored (holds Wi-Fi creds) so it does NOT
   travel with the repo. Create `secrets.h` next to the `.ino` with:
   ```cpp
   #pragma once
   #define SECRET_SSID "your-wifi-name"
   #define SECRET_PASS "your-wifi-password"
   #define OWM_API_KEY "your-openweathermap-key"   // weather mode
   ```
3. **Build/flash.** Two supported paths:
   - **PlatformIO** (used on the primary machine):
     ```
     pio run                 # compile
     pio run -t upload       # flash (set the right port in platformio.ini)
     pio device monitor -p COM3 -b 115200
     ```
     Board env is `esp32dev` (board `esp32doit-devkit-v1`). Libraries auto-resolve
     from `platformio.ini`. **Set `upload_port`/`monitor_port`** to the COM port on
     the new machine (it won't necessarily be COM3).
   - **Arduino IDE**: open `esp32-epaper-web.ino`, install the libraries listed in
     the README, select the ESP32 board + port, upload.
4. **Find the device IP** from the serial monitor (printed once Wi-Fi connects),
   browse to it, type text, **Update Display**.

> **Note:** the README's "Setup" section predates `secrets.h` and still says to
> put `ssid`/`password` directly in the `.ino`. The creds now come from
> `secrets.h` instead — recreate that file rather than editing the sketch.

---

## Repo layout / files

| File | Purpose |
|---|---|
| `esp32-epaper-web.ino` | The sketch (Wi-Fi + async web server + GxEPD2 draw). |
| `secrets.h` | Wi-Fi creds. **Gitignored** — recreate per machine (see above). |
| `logo.h` | Three Oak Woods badge SVG (from oaklink/branding), served at `/logo.svg`. |
| `platformio.ini` | PlatformIO build/flash config (env `esp32dev`). |
| `README.md` | Hardware, wiring, library list, panel-constructor notes. |
| `JOURNAL.md` | This file. |
| `epaper-sketch_jun24a.ino.bak` | Old static bring-up prototype. Local-only (gitignored), NOT built — won't be in a fresh clone. |

> **PlatformIO gotcha:** PlatformIO concatenates *every* `*.ino` in `src_dir`
> into one sketch. A second `.ino` causes `setup()`/`loop()`/`display`
> redefinition errors — that's why the old prototype carries a `.bak` extension.
> `build_src_filter` does **not** exclude `.ino` files.

---

## Log

### 2026-06-25 — OTA updates + fixed the OWM 401
- **OWM 401 wasn't a bad key.** Tested `ff86a6…` directly vs the OWM API — valid
  (returned live Greeley data). The deployed board just had a **stale/blank key**
  in its flash (restored with the key pending). Re-flashing from current
  `secrets.h` fixed it — weather fetches again (`valid:true`, "Greeley 84F").
- **OTA (`ArduinoOTA`)** added: hostname `epaper`, port 3232, `handle()` in loop,
  optional `OTA_PASSWORD` via secrets.h. New `[env:esp32dev_ota]` (espota,
  upload_port = device IP) → `pio run -e esp32dev_ota -t upload`.
- **Partition fix (the gotcha):** OTA needs **two app partitions**; `huge_app.csv`
  has only one, so OTA failed at 0%. Switched to **`min_spiffs.csv`** (2 × ~1.9 MB
  slots; fw is ~1.15 MB → 58.7%). Requires one **USB** flash to apply the new
  partition table, then OTA works.
- **Verified end-to-end:** serial-flashed the new scheme to the e-paper board
  (COM7, `24:0a:c4`), then flashed it **over Wi-Fi** (`Result: OK`, 100%); it
  rebooted clean and weather still valid. NVS persistence survived the change
  (nvs stays at 0x9000).
- platformio.ini `upload_port` updated COM3 → COM7 (board's current port).

### 2026-06-25 — Diagnosed "fried" board: MCU alive, panel not responding
- User plugged a battery into an e-paper board and feared it was fried. Checked
  the board on **COM7** (note: COM moved from COM3).
- **ESP32 is healthy:** esptool read it — ESP32-D0WDQ6 rev1.0, **MAC
  `24:0a:c4:12:88:18`**. Serial shows a clean POWERON boot, Wi-Fi connects, firmware
  runs ("Ready… http://192.168.12.50"). No brown-out loop / panic. MCU not fried.
- **Panel is the casualty (or unplugged):** GxEPD2 timings read `_Update_Full : 1`
  / `_PowerOn : 25` vs a healthy panel's `~2,150,000` / `~95,000` — i.e. the BUSY
  line never responds, so the panel isn't connected/powered/working.
- **Two-board surprise:** the board running live at .50 on the network is a
  *different* unit (**MAC `08:b6:1f:f0:01:64`**) — that's the one flashed/tested all
  session. The COM7 board (`24:0a:c4`) is the user's battery experiment. Both are
  set to **static .50 → IP conflict** if powered together.
- Side note: COM7 board's serial showed `OWM fetch failed: code=401` (stale/invalid
  OpenWeatherMap key on that board's flash).
- **Awaiting from user:** panel wiring/symptom + how the battery was wired, to tell
  panel-damage vs loose-connection apart. Offered a BUSY-pin test flash.

### 2026-06-25 — Text long messages: 4-line PAGING (partial scroll abandoned)
- **Partial-refresh line scroll didn't work on this panel** — overlaid/looked bad
  even after the no-hibernate fix. Abandoned it.
- **Final approach: paging.** When a message exceeds 4 lines, page it
  `TEXT_VISIBLE_LINES` (4) at a time — one **clean full refresh per page**, lines
  centered, `page/pages` indicator bottom-left. `textScroll` is now the page index;
  advance every `PAGE_MS` (5s) to the last page, then hold (`scrollDoneAt`).
  Auto-cycle waits `SCROLL_HOLD_MS` (5s) after the last page (short notes:
  TEXT_DWELL). Full refresh = no overlay, at the cost of a brief flash per page.
- **Font:** kept at **12pt** (`FreeSansBold12pt7b`, `LINE_HEIGHT 22`); 9pt was too
  small, user passed on a custom font.
- `drawText` no longer takes a `partial` arg.

### 2026-06-25 — Enclosure: refined exterior + real measured dims
- Brought in the user's refined `weather-epaper-refined.scad` as
  `enclosure/epaper-case.scad`: **measured display dims** (module 76.5×34.5×2.4,
  window 59.2×29.3, win_dx −1.0) and a redesigned exterior — beveled rear edge,
  wraparound accent band, chamfered faceplate, recessed display surround, beveled
  window opening, softened countersinks. Internals/cavity/ports unchanged.
- That refinement came off an older base, so it had dropped the **button hole**,
  **stand**, and **wall-mount keyholes** — re-added all three on top of the
  refined exterior (btn_d top hole, `stand` part, `wall_mount` keyholes).
- Re-rendered shell/front/stand STLs (all manifold-clean) + preview.

### 2026-06-25 — Persist the message box text
- `saveState()` now also writes `currentText` to NVS ("text" key); boot restores
  it (`prefs.getString("text", ...)`). Boot mode logic gained a `MODE_TEXT` branch
  so a saved message screen comes back after a power cycle (was: text reset to
  "Hello World!"; only mode+zip+cycle persisted).
- **Verified on hardware:** set "Persist me/line two", hard-rebooted (DTR/RTS) →
  came back as mode `text` with the message intact (was: reset to "Hello World!").

### 2026-06-25 — Made the web app a PWA (installable, home-screen)
- Added `webapp/manifest.webmanifest`, `webapp/sw.js`, and icons (192/512/apple-
  touch, from Three Oak Woods branding). index.html: manifest link, theme-color,
  apple-web-app meta, SW registration (guarded by `isSecureContext`), and an
  **Install app** button (`beforeinstallprompt`).
- Device serves the PWA assets: `/manifest.webmanifest` (absolute-path variant in
  `DEVICE_MANIFEST`), `/sw.js` (`DEVICE_SW`), `/icon-192.png` + `/apple-touch-icon.png`
  (from `icon.h`, a byte array via `xxd -i`). Verified all 200 w/ right MIME.
- **Key constraint documented:** service workers need a secure context; the device
  is HTTP, so no offline/auto-install-prompt there, BUT add-to-home-screen still
  gives a standalone app over HTTP (same-origin live data). HTTPS hosting would
  enable offline but mixed-content-block the HTTP device — so device-served HTTP
  is the right tradeoff. SW self-activates only if served from a secure origin.

### 2026-06-25 — Merged web-app → main; device serves the SPA at /app
- **Merged `web-app` into `main`** (fast-forward) — `/status.json`, CORS, the SPA,
  weather views, and the "Message" label are now on main.
- **Device bundles + serves the web app:** `webapp.h` is auto-generated from
  `webapp/index.html` (raw string literal, like `logo.h`) and served at **`/app`**.
  The control page got an **"Open the web app ↗"** link. SPA now defaults its host
  to `location.origin` when served over http (bundled copy targets the device
  automatically; standalone file falls back to the .50 guess).
- Verified: `/app` returns the SPA, link present on `/`. Regen note in webapp/README.
- (Still unverified on hardware: physical button + battery wiring.)

### 2026-06-25 — Weather views in the web app (`web-app` branch)
- Enriched **`/status.json`**: weather now includes `feels/humidity/wind/icon`;
  station includes `gustmph/dailyrain/baromin/winddir`.
- SPA `webapp/index.html` gained two **view cards**: a **Forecast** card (emoji
  icon via OWM code, big temp, city, condition, feels/humidity/wind) and a
  **Backyard station** card (temp, humidity, wind+compass, gust, rain, pressure).
  Moved the small weather/station stats out of the status card.
- Verified live: status.json shows Greeley 62F/79%/wind 3/icon 10n. JS syntax
  checked, div tags balanced. (Merged main into web-app first so the branch has
  battery/button/cycle/enclosure too.)

### 2026-06-25 — `web-app` branch: standalone browser SPA
*(this entry exists on the `web-app` branch)*
- Firmware (branch only): added **`/status.json`** (mode, ip, autoCycle, text,
  battery, weather, station via ArduinoJson) and a global
  **`Access-Control-Allow-Origin: *`** header (DefaultHeaders) so an off-device
  app can read it. `modeName()` helper added.
- **`webapp/index.html`** — single-file Three Oak Woods themed SPA: enter the
  device address (saved in localStorage), polls `/status.json` every 5 s, shows
  live status (battery, weather, station, auto-cycle), and drives all the
  existing GET endpoints (clock/weather/station/next/cycle/set/clear/refresh).
  Fires actions with `redirect:'manual'`. No build step / no deps.
- Verified `/status.json` + CORS header on device. To use: flash this branch,
  open `webapp/index.html`, connect to `http://192.168.12.50`.

### 2026-06-25 — Battery %, button cycling, auto-cycle, text scroll; case v2
- **Battery indicator:** GPIO34 via 2:1 divider, `analogReadMilliVolts`, mapped
  3.30–4.20 V → 0–100%. `readBattery()` auto-detects (shows only when plausible),
  battery glyph + % top-right of every screen (`drawOverlays`, renamed from
  `drawIpLabel`). `BATT_RATIO` configurable.
- **Physical button** GPIO27 `INPUT_PULLUP` → debounced in loop → `cycleScreen()`
  (Clock→Text→Weather→Station). Web equivalents: `/next` (P_CYCLE) and `/cycle`
  (toggle autoCycle, persisted to NVS "cycle").
- **Auto-cycle:** advances every `CYCLE_MS` (12 s), but `TEXT_DWELL_MS` (30 s) when
  on text with notes (`hasNotes()`).
- **Text scrolling:** `drawText` pages a 4-line window (`textScroll`, `lineCount`,
  `nthLine`) with a `n/total` indicator when >4 lines; `loop` advances every 4 s.
  Textarea bumped to rows=6/maxlength=400.
- **Enclosure v2:** added `btn_d` top button hole, `stand` part (easel/kickstand),
  optional `wall_mount` keyholes. STLs re-rendered (shell/front/stand), preview
  updated. Battery-sense + button wiring documented in enclosure/README.
- Verified on device via web: Clock→Text cycle, auto-cycle on/off, 6-line text set
  (scrolls). Button + battery are hardware-gated (logic in place, not yet wired).
- **Next:** `web-app` branch for a browser SPA hitting the device API.

### 2026-06-25 — Battery (18650 + load sharing) + 3D-printed enclosure
- Added an **`enclosure/`** project: parametric OpenSCAD case (`epaper-case.scad`)
  → shell + front plate, rendered to STLs (clean 2-manifold, no supports). Holds
  ESP32 on standoffs, 18650 in cradle saddles, charger module, USB slot + switch
  hole, 4 corner M2.5 screws. All dims are top-of-file variables (measure & tweak).
  OpenSCAD is installed at `C:\Program Files\OpenSCAD\openscad.exe`; re-render with
  `openscad -D 'part="shell"' -o x.stl epaper-case.scad`.
- **Power design (in enclosure/README):** load-sharing charger (Adafruit PowerBoost
  1000C recommended, IP5306 module as budget) → 5 V into ESP32 VIN. Bare TP4056 is
  NOT load-sharing — flagged. 18650 ~3000mAh → ~12–18 h (always-on server blocks
  deep sleep). Firmware unchanged (still just 5 V on VIN).
- Open follow-up offered: firmware **battery monitor** (18650+ via divider → ADC →
  show battery % on the panel). Not built yet.

### 2026-06-25 — STATION DATA FLOWING. Fixed the `&` vs `?` URL quirk
- Console finally pushed once Server was set to 192.168.12.50, but sent
  `query=0 NO FIELDS PARSED`. Full `/debug` dump revealed why: the **AMBWeatherPro
  console joins params with `&` not `?`** — URL was
  `/data/report/&PASSKEY=...&tempf=64.0&humidity=71&...` (User-Agent: `AMBWeatherPro`).
  No `?` delimiter → server parses nothing, even though all fields are present.
- **Fix:** in `onReport`, grab the URL tail after the first `?`/`&` and parse it
  with `fromBody()` (added as a source in `rd()`). Now works with the console's
  stock config — no special Path needed. Verified: live "Station — 64F, Hum 72%,
  Wind 3", pushes every 60s from .190 parsing cleanly.
- Added a full-request dump to `/debug` (method/url/headers/params/body) — that's
  what exposed the `&` quirk. Keep it; invaluable for this kind of thing.
- Note: boot restore currently only handles WEATHER→weather else clock; STATION
  isn't restored on boot (would show "waiting" then fill). Offered to add.

### 2026-06-24 — Static IP (T-Mobile gateway has no DHCP reservation)
- **Root issue all along:** the console's "Customized" Server field was **blank**,
  so it never pushed. `/debug` proved it — only this PC's IP (.112) ever hit
  `/data/report`, never the console (.190). The station never sent anything.
- T-Mobile 5G Gateway has **no DHCP reservation** option, so pinned the ESP with a
  **firmware static IP** instead. `WiFi.config()` guarded by `USE_STATIC_IP` in
  `secrets.h`. Chose **192.168.12.50** — ARP showed ~70 devices all in .107–.246
  (pool starts ~.107), so .2–.99 is below the pool and safe; pinged .50/.40/.30/.60
  all free. ESP now at **192.168.12.50**; DNS/NTP/weather verified working there.
- ESP MAC = `08:B6:1F:F0:01:64`. Console = `192.168.12.190` (MAC 40:91:51:59:9E:A3).
- **User action still needed:** set the console's Customized Server to
  **192.168.12.50**, Path `/data/report/`, Port 80, AmbientWeather, and Save.

### 2026-06-24 — NTP clock (default view) + NVS persistence
- **Clock mode (`MODE_CLOCK`, now the default):** NTP via `configTzTime(TZ_INFO,...)`,
  `TZ_INFO="MST7MDT,M3.2.0,M11.1.0"` (Mountain, auto DST). `drawClock()` centers a
  big time (24pt) + date (12pt); shows "Syncing time..." until NTP locks; ticks
  once per minute in loop (full refresh each minute — flashes; flagged to user).
  "Show Clock" button + `/clock` endpoint.
- **Persistence (NVS via `Preferences`, namespace "epaper"):** `saveState()` writes
  `mode` + `zip` on every view change. Boot restores: saved `mode==WEATHER` && zip
  → weather; else clock. Verified across a real reboot — saved ZIP 80631 came back
  as "Weather — Greeley" after reset.
- **Station pull vs push reminder:** the console PUSHES to
  `http://<esp-ip>/data/report/`; the ESP never pulls from the station. (OWM is the
  only outbound pull: `api.openweathermap.org/data/2.5/weather`.)
- Note: clock's per-minute full refresh is aggressive on panel life; could switch
  to partial refresh or coarser interval if wear becomes a concern.

### 2026-06-24 — Fix station push parsing (POST) + /debug diagnostics
- **Root cause of "/data/report/ failing":** the console likely POSTs the readings
  in the request body, but the handler only read the **query string** → zero fields
  parsed, panel stuck on "no data". Now reads each field **query → POST param →
  raw body** (`rd()` + `fromBody()`). Confirmed: simulated POST parses `tempf`.
- The `/data/report/` traffic is **local** — it's the console (its LAN IP) doing
  outbound pushes, NOT ambientweather.net. The cloud never connects into the LAN.
- Added **`/debug`** (recent hits: method, source IP, param count, parsed tempf,
  + last raw body) and an `onNotFound` that logs 404s — so wrong path/method from
  the real console is visible without a serial monitor.

### 2026-06-24 — Deep-refresh (de-ghost) + station waiting timeout
- **Deep refresh** `deepRefresh()`: flashes the panel black↔white x2 to scrub
  SSD1680 ghosting, then `redrawCurrent()` restores the view. Runs automatically
  every 6 h (`DEEP_REFRESH_MS`) and on demand via a **Clean (de-ghost)** button
  (`/refresh` → `P_DEEP`). Resolves the humidity-digit ghosting seen earlier.
- **Station "waiting" no longer looks hung:** the waiting screen shows a live
  `(Ns)` counter and redraws every 20 s; after 90 s (`STATION_WAIT_MS`) with no
  push it **falls back** to weather (if a ZIP is set) or text. `stationModeSince`
  set when `/station` is tapped. Verified: fell back to "Weather — Greeley" after
  ~90 s of no data.

### 2026-06-24 — IP to lower-right + weather detail overflow fix
- IP label moved to the **lower-right** corner only (`drawIpLabel()`,
  right-aligned by `len*6`). Briefly tried both corners; user wanted right only.
- Staying on **DHCP** (no static IP in firmware) — DHCP reservation handles the
  stable address for the station push.
- Fixed weather **detail line overflowing** the 250px width (real panel photo
  showed "Wind" with its value cut off): tightened `wx.detail` — dropped the "F"
  after feels, triple→double spaces.
- Open: a photo showed faint **ghosting** on the humidity digits ("58%" with a
  prior value behind). Likely SSD1680 ghosting; remedy if it bothers: periodic
  deep full-refresh / clearScreen pass. Not done yet.

### 2026-06-24 — Local Ambient Weather station (push) + layout mockup
- **Third mode: Backyard Station.** The ESP32 now ingests the Ambient Weather
  console's "Customized" upload (AmbientWeather protocol) at **`/data/report/`** —
  fully local, no API key, real backyard sensors. Parses `tempf, humidity,
  windspeedmph, windgustmph, winddir, dailyrainin, baromrelin` from the query
  string, stores them in `struct Station st`, replies `200 OK`. Panel **redraws on
  each push** while in station mode (handler sets `pending=P_STATION`).
- `drawStation()`: big outdoor temp (left) + stat column (humidity, wind+compass,
  gust, rain) + pressure, IP bottom-left. `compass()` maps winddir° → 16-point.
  Shows "Waiting for station data" until the first push arrives.
- Page gets a **Backyard Station** card (Show Station) + a live summary line;
  `/station` endpoint queues `P_STATION`. Added `MODE_STATION` / `P_STATION`.
- **Why push over the AmbientWeather.net cloud API:** no keys, offline-resilient,
  the console's Customized server field was empty/unused. Cloud upload still runs
  in parallel, untouched.
- **Console config** (their device = AMBWeatherPro_V5.2.7): Customized=Enable,
  Protocol=AmbientWeather, Server=<ESP32 IP>, Path=`/data/report/`, Port=80,
  Interval=60. ESP32 needs a **stable IP** (DHCP reservation) so the console keeps
  reaching it — currently DHCP .184. Static-IP-in-firmware not added yet (offered).
- **Verified** with a simulated push: `tempf=72.5&humidity=68&windspeedmph=8...`
  → status "Station — 73F, Hum 68%, Wind 8". Real console not yet pointed at it.
- Also rendered an SVG mockup of the weather-mode panel layout for reference.

### 2026-06-24 — Fancy weather: OpenWeatherMap + drawn icons
- **Switched weather source wttr.in → OpenWeatherMap** (current-weather endpoint,
  `units=imperial`). Key lives in `secrets.h` as `OWM_API_KEY` (gitignored). JSON
  parsed with **ArduinoJson** (added to `lib_deps`). Now gets the real **city
  name** (wttr.in only echoed the ZIP), plus feels-like / humidity / wind / icon.
- **Fancy panel layout** (`drawWeather()`): city header + divider rule, a drawn
  **weather icon** on the left, **big temperature** (FreeSansBold24pt) with a
  hand-drawn degree ring + small "F", condition text, and a feels/hum/wind detail
  line — IP still bottom-left. Added fonts FreeSansBold9pt7b + FreeSansBold24pt7b.
- **Weather icons** are 1-bit GFX primitives (`drawSun/drawCloud/drawRain/drawSnow/
  drawBolt/drawMist`) mapped from the OWM icon code (`01`–`50`) — no bitmaps.
- **Partition bump:** `board_build.partitions = huge_app.csv` (3MB app) since fonts
  + TLS + JSON pushed the default ~1.3MB partition close. Firmware ~1.03MB.
- **Verified:** ZIP 94103 → "San Francisco 61F, Few clouds" parsed and drawn.
- Wi-Fi: SSID "Three Oak Wood". (Reminder: `pio device monitor` resets the board.)

### 2026-06-24 — Weather mode + Three Oak Woods themed page
- **Two display modes:** Text (existing) and **Weather**. The page now has a Text
  card and a Weather card; the Weather card asks for a US **ZIP** ("Show Weather"),
  which is how you switch into weather mode. `mode` (MODE_TEXT/MODE_WEATHER) +
  `weatherZip`/`weatherText` track state.
- **Weather source:** wttr.in, **no API key** — takes the ZIP directly and returns
  a one-line `%l|%t|%C` format we split (no JSON lib). HTTPS via `WiFiClientSecure`
  + `setInsecure()`, `User-Agent: curl/*` so wttr returns plain text. Output is
  ASCII-filtered (`asciiOnly()`) to drop the degree sign / wind arrows the 12pt
  font can't render. Panel shows ZIP / temp / condition; **auto-refresh every 15
  min** while in weather mode. (wttr.in echoes the ZIP as the location label, so
  line 1 is the ZIP, not the city name — could fetch the city separately later.)
- **Concurrency fix:** web handlers no longer draw/fetch inline. They set a
  `Pending` action (P_TEXT/P_WEATHER/P_CLEAR) and `loop()` executes it. Keeps
  blocking SPI/TLS off the AsyncTCP task and avoids two tasks hitting the display.
- **Three Oak Woods theme:** page restyled with the company palette (Forest Green
  `#2C654B`, Cream, Acorn Amber, Bark, Parchment), Nunito font, and the acorn
  **badge logo** (`logo.h`, served at `/logo.svg`) in the header + as favicon.
  Assets/colors pulled from `oaklink/branding/`.
- **Verified on hardware:** ZIP 94103 → "94103 / 68F / Partly Cloudy" drawn; text
  mode round-trips; page + logo + favicon serve correctly. Firmware ~1 MB now
  (TLS stack). Note: opening `pio device monitor` resets the board (DTR/RTS), so
  test HTTP endpoints *without* a monitor attached, or expect a reboot race.

### 2026-06-24 — Persistent IP label + README/repo refresh
- **IP on panel:** the device IP now renders in the built-in 6x8 font at the
  bottom-left **at all times** — on both `drawText()` and `clearDisplay()`, so it
  survives a Clear. New `ipText` global + `drawIpLabel()` helper (called inside
  the paged-draw loop). Boot draw moved to *after* Wi-Fi connects so the first
  render already has the IP. Note: paged drawing reruns the draw block per page,
  so the big font is re-selected each page (the label switches to the small font).
- **README:** Setup section rewritten for `secrets.h` (no more editing creds in
  the `.ino`) and documents both PlatformIO and Arduino IDE flashing.
- **Repo:** project is now an actual git repo, pushed to
  https://github.com/jdburgie/esp32-epaper-web (private). The earlier note that
  this repo already existed was wrong — created it fresh today.

### 2026-06-24 — Multi-line + clear-screen, moved to PlatformIO
- **Multi-line text:** swapped the single-line `<input>` for a `<textarea rows=4>`
  (Enter = newline), bumped `maxlength` 80→120. `drawText()` now counts `\n`,
  computes block height (`lines * LINE_HEIGHT`, `LINE_HEIGHT 22`), centers the
  block vertically, and centers each line horizontally on its own width. `/set`
  strips `\r` (browsers send `\r\n` from textareas).
- **Clear-screen button:** new `clearDisplay()` (white full-window fill +
  hibernate) and a `/clear` GET endpoint, with a secondary "Clear Screen" button
  under the update form. Both handlers `redirect("/")` *before* the ~2s redraw so
  the browser doesn't hang.
- **Tooling:** added `platformio.ini` and started building/flashing with
  PlatformIO (arduino-cli not installed). First build failed on a duplicate
  `.ino` (the old bring-up prototype) — renamed it to `.ino.bak`.
- **Creds:** moved Wi-Fi creds out of the sketch into gitignored `secrets.h`;
  `.gitignore` now also covers `.pio/`, `secrets.h`, `*.ino.bak`.
- **Verified on hardware:** flashed to the DevKit (COM3), joined Wi-Fi, served the
  updated UI; a 3-line test message rendered centered and evenly spaced —
  `LINE_HEIGHT 22` looks right, no adjustment needed.

### (earlier) — Initial build
- Got the FPC-A002 / SSD1680 2.13" panel drawing with `GxEPD2_213_BN`.
- Added Wi-Fi + ESPAsyncWebServer; browser form updates the displayed text.
- Panel hibernates between updates for burn-in protection; no deep sleep because
  the web server needs the chip awake.

---

## Open follow-ups (not started)

- **TODO (2026-07-15): wire the e-paper panel to the deployed board.** The
  deployed device at `.50` is now the **ESP8266/ESP-12E** board (the old ESP32
  unit `24:0a:c4` is retired) — panel has never been physically wired to it.
  Use the ESP8266 pin map in README's "ESP8266 (ESP-12E) port" section (avoids
  the boot-strap traps, esp. D8/GPIO15). Display output is completely untested
  on this board.
- **TODO (2026-07-15): battery sense on the ESP8266 board** — divider not wired
  yet, and even once wired it needs **empirical per-board calibration**
  (`BATT_ESP8266_FULLSCALE_V`, no fixed ESP32-style formula works on ESP8266's
  ADC). See README.
- ~~TODO: e-paper board (`24:0a:c4`, .50) panel~~ **MOOT** — that board is
  retired; superseded by the ESP8266 panel-wiring TODO above.
- ~~TODO (2026-06-25): add weather views to the web page~~ **DONE** — SPA Forecast
  + Backyard station cards; `/status.json` enriched. Web app now served at `/app`.
- **TODO (2026-06-25): "remember test"** — read as: test the new button + battery
  on real hardware once wired (GPIO27 button, GPIO34 divider). *Awaiting
  confirmation that this is what was meant.*
- Cap rendered lines at 4 (the textarea allows more than fit the 122px panel);
  truncate or warn on overflow.
- Per-line auto-shrink to a smaller font when a line exceeds the 250px width.
- Possible later: partial-window refresh for snappier redraws (currently
  full-window, which flashes black/white each update).

---

## Estimated AI footprint

Rough, unverifiable estimate of the data-center water used by the AI assistant
across this project's build sessions: **on the order of ~1 gallon (~4 L), with at
least a 10× uncertainty band either way** — plausibly a couple of cups, plausibly
a few gallons. There is no per-conversation meter; this is extrapolated from
published per-query ranges, which are themselves contested and vary widely by
data-center cooling and location.

- **Caveat:** order-of-magnitude only; do not cite as measured. Local work
  (firmware compiles/flashes, OpenSCAD renders, `curl` tests) ran on the dev PC —
  ordinary wall power, negligible water.
- **Source:** P. Li, J. Yang, M. A. Islam, S. Ren, *"Making AI Less 'Thirsty':
  Uncovering and Addressing the Secret Water Footprint of AI Models,"* 2023
  (arXiv:2304.03271).

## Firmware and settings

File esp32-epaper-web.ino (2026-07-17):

/*
 * ESP32 E-Paper Web Display
 * --------------------------
 * NodeMCU ESP32 DevKit V1 (30-pin) + Inland 2.13" e-paper driver board.
 * Panel: FPC-A002 ribbon, 2.13" 250x122 b/w, SSD1680 controller.
 *
 * Type text in a browser on the same Wi-Fi network and the panel redraws.
 *
 * Wiring (Inland driver board -> ESP32):
 *   SDI (MOSI) -> GPIO23      D/C  -> GPIO19
 *   SCLK (CLK) -> GPIO18      RES  -> GPIO16 (RX2)
 *   CS         -> GPIO5       BUSY -> GPIO4
 *   VCC -> 3V3   GND -> GND   (driver switch P2 set to 3.3VIN)
 *
 * Libraries: GxEPD2, Adafruit GFX, ESPAsyncWebServer, AsyncTCP.
 *
 * NOTE: deep sleep and the web server are mutually exclusive. The ESP32
 * stays awake to serve requests; the PANEL still hibernates between
 * updates, which is what prevents burn-in/ghosting.
 */

#if defined(ESP32)
  #include <WiFi.h>
  #include <WiFiClientSecure.h>
  #include <HTTPClient.h>
  #include <Preferences.h>
#elif defined(ESP8266)
  #include <ESP8266WiFi.h>
  #include <WiFiClientSecure.h>     // ESP8266 core wraps BearSSL; same .setInsecure() API
  #include <ESP8266HTTPClient.h>
  #include <LittleFS.h>
#endif
#include <ArduinoOTA.h>
#include <ArduinoJson.h>
#include <ESPAsyncWebServer.h>
#include <time.h>
#include <GxEPD2_BW.h>
#include <Fonts/FreeSansBold9pt7b.h>
#include <Fonts/FreeSansBold12pt7b.h>
#include <Fonts/FreeSansBold24pt7b.h>
#include "secrets.h"   // SECRET_SSID / SECRET_PASS / OWM_API_KEY (gitignored)
#include "logo.h"      // THREEOAKWOODS_BADGE_SVG, served at /logo.svg
#include "webapp.h"    // WEBAPP_HTML (SPA / PWA), served at /app
#include "icon.h"      // webapp_icon_192_png[], served as the PWA icon

// PWA manifest the DEVICE serves (absolute paths for the /app origin). The copy
// in webapp/ uses relative paths for standalone/hosted use.
const char DEVICE_MANIFEST[] PROGMEM = R"MANIFEST({
  "name":"Three Oak Woods E-Paper","short_name":"E-Paper","start_url":"/app","scope":"/",
  "display":"standalone","background_color":"#F5F1E6","theme_color":"#2C654B",
  "icons":[{"src":"/icon-192.png","sizes":"192x192","type":"image/png","purpose":"any"},
           {"src":"/logo.svg","sizes":"any","type":"image/svg+xml","purpose":"any maskable"}]
})MANIFEST";

// Service worker the device serves (only runs if the origin is secure; harmless on HTTP).
const char DEVICE_SW[] PROGMEM = R"SWJS(const CACHE='epaper-dev-v1';
const SHELL=['/app','/manifest.webmanifest','/icon-192.png','/logo.svg'];
self.addEventListener('install',e=>{e.waitUntil(caches.open(CACHE).then(c=>c.addAll(SHELL)).then(()=>self.skipWaiting()));});
self.addEventListener('activate',e=>{e.waitUntil(self.clients.claim());});
self.addEventListener('fetch',e=>{const p=new URL(e.request.url).pathname;
if(/(\/status\.json|\/(set|weather|station|clock|next|cycle|clear|refresh))/.test(p))return;
e.respondWith(caches.match(e.request).then(r=>r||fetch(e.request)));});
)SWJS";

// POSIX timezone for the clock — Mountain Time (Greeley, CO), auto DST.
#define TZ_INFO "MST7MDT,M3.2.0,M11.1.0"

// ---- Wi-Fi ----
const char* ssid     = SECRET_SSID;
const char* password = SECRET_PASS;

// ---- Pins ----
#if defined(ESP32)
  #define EPD_CS    5
  #define EPD_DC    19
  #define EPD_RST   16
  #define EPD_BUSY  4
  #define PIN_BTN   27    // momentary button (to GND) — cycles screens
  #define PIN_BATT  34    // 18650 voltage via 2:1 divider (ADC1, input-only)
  #define BATT_RATIO 2.0  // divider multiplier (100k/100k = 2.0)
#elif defined(ESP8266)
  // NodeMCU D-pin -> GPIO map. Hardware SPI (SCK=D5/GPIO14, MOSI=D7/GPIO13) is
  // fixed and used automatically by GxEPD2 — not defined here. D8/GPIO15 is
  // deliberately AVOIDED: it must read LOW at boot, and an e-paper driver
  // board's CS-idle pull-up on that line can prevent the ESP8266 from booting.
  // CS/DC/RST are outputs WE drive after boot (safe on D3/D4's boot-strap
  // pins, since we don't touch them until setup() runs); BUSY (driven BY the
  // display) and the button sit on D2/D1, which carry no boot-strap meaning.
  #define EPD_CS    0     // D3 (GPIO0)  - output, onboard pull-up
  #define EPD_DC    2     // D4 (GPIO2)  - output, onboard pull-up (shares the onboard LED)
  #define EPD_RST   16    // D0 (GPIO16) - output, no boot-strap meaning
  #define EPD_BUSY  4     // D2 (GPIO4)  - input from display, no boot-strap meaning
  #define PIN_BTN   5     // D1 (GPIO5)  - input w/ pullup, no boot-strap meaning
  #define PIN_BATT  A0    // the only analog pin on ESP8266
  // Full-scale volts at raw=1023. ESP8266 has ONE 0-1V ADC; NodeMCU boards add
  // an onboard divider of unknown-to-us ratio, and we add our OWN 100k/100k
  // divider on top (same physical design as the ESP32 board) so the input to
  // A0 never exceeds ~half the cell voltage regardless of board variant — safe
  // by design, but the exact combined ratio must be CALIBRATED: connect a
  // charged cell through the divider, compare a multimeter reading to
  // analogRead(A0), and set this to (multimeter volts) / (raw/1023.0).
  #define BATT_ESP8266_FULLSCALE_V 4.2
#endif

// ---- Panel: FPC-A002 2.13" 250x122, SSD1680 ----
// If this comes up blank/garbled, try _213_B74, then _213_B73, then _213_B72.
GxEPD2_BW<GxEPD2_213_BN, GxEPD2_213_BN::HEIGHT> display(
    GxEPD2_213_BN(EPD_CS, EPD_DC, EPD_RST, EPD_BUSY));

AsyncWebServer server(80);

String currentText  = "Hello World!";
String ipText       = "";   // set once Wi-Fi connects (or AP starts); shown bottom-left always
bool apMode         = false; // true when running as a Wi-Fi-setup AP instead of on the real network

#if defined(ESP8266)
// Minimal Preferences-alike backed by one JSON file on LittleFS, so the rest of
// the sketch (prefs.getString/putString/getInt/putInt/getBool/putBool) works
// unchanged on both ESP32 (real NVS Preferences) and ESP8266 (this shim).
// ESP8266 has no NVS/Preferences library — LittleFS + ArduinoJson is the
// standard substitute, and handles the variable-length message text cleanly.
class FilePrefs {
  JsonDocument doc;
  const char* path = "/prefs.json";
  void load() { File f = LittleFS.open(path, "r"); if (f) { deserializeJson(doc, f); f.close(); } }
  void save() { File f = LittleFS.open(path, "w"); if (f) { serializeJson(doc, f); f.close(); } }
public:
  void   begin(const char*, bool) { LittleFS.begin(); load(); }
  String getString(const char* k, const String& def = "") { return doc[k] | def; }
  void   putString(const char* k, const String& v)        { doc[k] = v; save(); }
  int    getInt(const char* k, int def = 0)                { return doc[k] | def; }
  void   putInt(const char* k, int v)                      { doc[k] = v; save(); }
  bool   getBool(const char* k, bool def = false)           { return doc[k] | def; }
  void   putBool(const char* k, bool v)                     { doc[k] = v; save(); }
};
FilePrefs prefs;
#elif defined(ESP32)
Preferences prefs;                  // NVS: remembers last mode + ZIP across power loss
#endif

// ---- Display mode + weather state ----
enum DisplayMode { MODE_TEXT, MODE_WEATHER, MODE_STATION, MODE_CLOCK };
DisplayMode mode    = MODE_CLOCK;   // clock is the default view
int lastClockMin = -1;              // last minute drawn, so the clock redraws on change
String weatherZip   = "";   // last ZIP requested
String weatherText  = "";   // short summary, shown on the web page

// Parsed OpenWeatherMap result for the current ZIP.
struct Wx {
  String city, cond, icon, detail;
  int    temp = 0, feels = 0, humidity = 0, wind = 0;
  bool   valid = false;
} wx;

// Live data pushed by the Ambient Weather console to /data/report/ (its
// "Customized" upload, AmbientWeather protocol). NAN/-1/"" = field not reported.
// Full field set the console actually sends (captured via /debug) — the curated
// panel/summary views only use a subset; the web app's "all data" view uses all.
struct Station {
  // Outdoor — core (used by the panel + curated summary)
  float tempf = NAN, humidity = NAN, windmph = NAN, gustmph = NAN;
  float dailyrain = NAN, baromin = NAN;
  int   winddir = -1;
  // Outdoor — extended
  float windmph10m = NAN, maxdailygust = NAN;
  int   winddir10m = -1;
  float uv = NAN, solarradiation = NAN;
  float hourlyrain = NAN, eventrain = NAN, weeklyrain = NAN, monthlyrain = NAN, yearlyrain = NAN;
  float baromabsin = NAN;
  // Indoor
  float tempinf = NAN, humidityin = NAN;
  // Sensor battery flags + lightning
  int   battout = -1, battin = -1, batt_lightning = -1, lightning_day = -1;
  // Meta
  String dateutc, stationtype;
  unsigned long lastUpdate = 0;   // millis() of last push
  bool  received = false;
} st;

String reqLog;     // recent /data/report hits (newest first), viewable at /debug
String lastBody;   // raw body of the most recent push, viewable at /debug
String lastReq;    // full dump (method/url/headers/params/body) of last /data/report hit

// All panel drawing + the weather fetch run from loop(), never inside an async
// web handler — that keeps blocking SPI/TLS work off the AsyncTCP task and
// avoids two tasks touching the display at once. Handlers just queue an action.
enum Pending { P_NONE, P_TEXT, P_WEATHER, P_CLEAR, P_STATION, P_DEEP, P_CLOCK, P_CYCLE };
volatile Pending pending = P_NONE;

// Battery monitor — auto-shows only when a plausible 18650 voltage is present.
float battVolts = 0; int battPct = -1; bool battValid = false;
unsigned long lastBatt = 0;
const unsigned long BATT_MS = 5UL * 1000UL;   // sample every 5 s (responsive while wiring)

// Screen cycling (auto). Physical button advances manually regardless.
bool autoCycle = false;
unsigned long lastCycle = 0;
const unsigned long CYCLE_MS      = 12UL * 1000UL;   // normal dwell per screen
const unsigned long TEXT_DWELL_MS = 30UL * 1000UL;   // longer dwell when text has notes
int btnReading = HIGH, btnStable = HIGH; unsigned long btnTime = 0;

// Text paging — when the message is taller than the panel, page TEXT_VISIBLE_LINES
// at a time (one clean full refresh per page) and stop on the last page.
#define TEXT_VISIBLE_LINES 4
int textScroll = 0; unsigned long lastScroll = 0;    // textScroll = current page index
unsigned long scrollDoneAt = 0;                      // millis when the last page was reached
const unsigned long PAGE_MS        = 5UL * 1000UL;   // per-page hold (reading time)
const unsigned long SCROLL_HOLD_MS = 5UL * 1000UL;   // wait after the last page before auto-cycle

unsigned long lastWxFetch = 0;
const unsigned long WX_REFRESH_MS = 5UL * 60UL * 1000UL;  // refresh weather every 5 min

unsigned long lastDeep = 0;
const unsigned long DEEP_REFRESH_MS = 6UL * 60UL * 60UL * 1000UL;  // scrub ghosting every 6 h

// Station "waiting for data" handling: show a live counter, then fall back so the
// panel never looks hung if the console isn't pushing yet.
unsigned long stationModeSince = 0;
unsigned long lastWaitDraw     = 0;
const unsigned long STATION_WAIT_MS = 90UL * 1000UL;   // give up waiting after 90 s
const unsigned long WAIT_REDRAW_MS  = 20UL * 1000UL;   // refresh the waiting screen every 20 s

// Line spacing for the message font FreeSansBold12pt7b (~17px glyphs + spacing).
#define LINE_HEIGHT 22

// Keep only printable ASCII (0x20-0x7E). The 12pt font has no glyphs for the
// degree sign / wind arrows wttr.in returns, so strip them before drawing.
String asciiOnly(const String& s) {
  String out; out.reserve(s.length());
  for (uint16_t i = 0; i < s.length(); i++) {
    char c = s[i];
    if (c >= 0x20 && c <= 0x7E) out += c;
  }
  out.trim();
  return out;
}

// Truncate to n chars with a trailing '.' if clipped (keeps long city/condition
// strings from overflowing the panel width).
String truncate(const String& s, uint8_t n) {
  if (s.length() <= n) return s;
  return s.substring(0, n - 1) + ".";
}

// ---- Battery: read the 18650 via the divider; auto-detect if wired ----
void readBattery() {
#if defined(ESP32)
  uint32_t mv = analogReadMilliVolts(PIN_BATT);   // factory-calibrated on ESP32
  float v = mv * BATT_RATIO / 1000.0;
#elif defined(ESP8266)
  int raw = analogRead(PIN_BATT);                 // 0-1023, ESP8266's only ADC
  float v = (raw / 1023.0) * BATT_ESP8266_FULLSCALE_V;
#endif
  if (v > 2.8 && v < 4.5) {                        // plausible cell -> battery present
    battVolts = v;
    battPct   = constrain((int)round((v - 3.30) / (4.20 - 3.30) * 100.0), 0, 100);
    battValid = true;
  } else {
    battValid = false;                             // floating pin / no cell -> hide
  }
}

// ---- Line helpers for the text screen ----
uint8_t lineCount(const String& s) {
  uint8_t n = 1;
  for (uint16_t i = 0; i < s.length(); i++) if (s[i] == '\n') n++;
  return n;
}
String nthLine(const String& s, uint8_t n) {
  int start = 0;
  for (uint8_t i = 0; i < n; i++) {
    int nl = s.indexOf('\n', start);
    if (nl < 0) return "";
    start = nl + 1;
  }
  int nl = s.indexOf('\n', start);
  return (nl < 0) ? s.substring(start) : s.substring(start, nl);
}
bool hasNotes() { String t = currentText; t.trim(); return t.length() > 0; }

// Push a line onto the small in-memory request log shown at /debug.
void logReq(const String& s) {
  reqLog = s + "\n" + reqLog;
  if (reqLog.length() > 1800) reqLog = reqLog.substring(0, 1800);
}

// Pull key=value out of a urlencoded body (fallback when params aren't parsed).
String fromBody(const String& body, const char* key) {
  String k = String(key) + "=";
  int i = body.indexOf(k);
  if (i < 0) return String();
  i += k.length();
  int e = body.indexOf('&', i);
  return body.substring(i, e < 0 ? body.length() : e);
}

// ---- Overlays drawn on every screen: IP (bottom-right) + battery (top-right) ----
// Call from inside a firstPage/nextPage loop. Built-in 6x8 font; 6 px/glyph.
void drawOverlays() {
  display.setFont(NULL);
  display.setTextSize(1);
  display.setTextColor(GxEPD_BLACK);

  // IP, bottom-right
  if (ipText.length())
    { display.setCursor(display.width() - ipText.length() * 6 - 2, display.height() - 8);
      display.print(ipText); }

  // Battery, top-right: "82% [###  ]"
  if (battValid) {
    String p = String(battPct) + "%";
    int by = 2, bodyW = 16, bodyH = 9;
    int iconX = display.width() - bodyW - 4;          // leave 2px for the nub
    int pctX  = iconX - (int)p.length() * 6 - 3;
    display.setCursor(pctX, by + 1); display.print(p);
    display.drawRect(iconX, by, bodyW, bodyH, GxEPD_BLACK);
    display.fillRect(iconX + bodyW, by + 2, 2, bodyH - 4, GxEPD_BLACK);   // nub
    display.fillRect(iconX + 1, by + 1, (bodyW - 2) * battPct / 100, bodyH - 2, GxEPD_BLACK);
  }
}

// ---- Blank the panel to all-white (IP label stays) ----
void clearDisplay() {
  display.setRotation(1);
  display.setFullWindow();
  display.firstPage();
  do {
    display.fillScreen(GxEPD_WHITE);
    drawOverlays();
  } while (display.nextPage());
  display.hibernate();  // panel sleeps between updates -> no burn-in
}

// ---- Draw msg with '\n' line breaks. Centers if it fits in TEXT_VISIBLE_LINES;
//      otherwise PAGES it 4 lines at a time (page = textScroll), one clean full
//      refresh per page, with a "page/pages" indicator bottom-left. ----
void drawText(const String& msg) {
  display.setRotation(1);
  display.setTextColor(GxEPD_BLACK);
  display.setFullWindow();

  uint8_t total     = lineCount(msg);
  uint8_t pages     = (total + TEXT_VISIBLE_LINES - 1) / TEXT_VISIBLE_LINES;   // ceil
  bool    paging    = pages > 1;
  uint8_t page      = paging ? (uint8_t)min((int)textScroll, (int)pages - 1) : 0;
  uint8_t startLine = page * TEXT_VISIBLE_LINES;
  uint8_t shown     = (uint8_t)min((int)TEXT_VISIBLE_LINES, (int)(total - startLine));

  display.firstPage();
  do {
    display.fillScreen(GxEPD_WHITE);
    display.setFont(&FreeSansBold12pt7b);   // re-select each page; overlays use the built-in font

    int16_t yTop = (display.height() - shown * LINE_HEIGHT) / 2;   // center this page's lines

    for (uint8_t k = 0; k < shown; k++) {
      String line = nthLine(msg, startLine + k);
      int16_t tbx, tby; uint16_t tbw, tbh;
      display.getTextBounds(line, 0, 0, &tbx, &tby, &tbw, &tbh);
      int16_t x = (display.width() - tbw) / 2 - tbx;
      int16_t y = yTop + k * LINE_HEIGHT - tby;
      display.setCursor(x, y);
      display.print(line);
    }

    if (paging) {   // "page/pages" indicator, bottom-left
      display.setFont(NULL); display.setTextSize(1);
      display.setCursor(2, display.height() - 8);
      display.print(String(page + 1) + "/" + String(pages));
    }

    drawOverlays();
  } while (display.nextPage());
  display.hibernate();
}

// ===== Weather icons: 1-bit glyphs drawn with GFX primitives, centered (cx,cy) =====
void drawSun(int cx, int cy, int r) {
  display.fillCircle(cx, cy, r, GxEPD_BLACK);
  for (int a = 0; a < 360; a += 45) {
    float t = a * 0.0174533f;
    display.drawLine(cx + cos(t) * (r + 4), cy + sin(t) * (r + 4),
                     cx + cos(t) * (r + 11), cy + sin(t) * (r + 11), GxEPD_BLACK);
  }
}
void drawCloud(int cx, int cy, int s) {  // filled silhouette; s ~ half-width
  display.fillCircle(cx - s * 0.5, cy, s * 0.42, GxEPD_BLACK);
  display.fillCircle(cx + s * 0.5, cy, s * 0.5,  GxEPD_BLACK);
  display.fillCircle(cx,           cy - s * 0.4, s * 0.55, GxEPD_BLACK);
  display.fillRect(cx - s * 0.5, cy, s, s * 0.5, GxEPD_BLACK);
}
void drawRain(int cx, int cy) {
  for (int i = -1; i <= 1; i++) display.drawLine(cx + i * 10, cy, cx + i * 10 - 4, cy + 9, GxEPD_BLACK);
}
void drawSnow(int cx, int cy) {
  for (int i = -1; i <= 1; i++) display.fillCircle(cx + i * 10, cy + 4, 2, GxEPD_BLACK);
}
void drawBolt(int cx, int cy) {
  display.fillTriangle(cx - 4, cy - 6, cx + 5, cy - 6, cx - 2, cy + 3, GxEPD_BLACK);
  display.fillTriangle(cx + 4, cy - 1, cx - 3, cy + 9, cx + 2, cy + 1, GxEPD_BLACK);
}
void drawMist(int cx, int cy) {
  for (int i = 0; i < 4; i++) display.drawFastHLine(cx - 18, cy - 9 + i * 7, 36, GxEPD_BLACK);
}
// Map an OpenWeatherMap icon code ("01d","10n",...) to a glyph.
void drawWeatherIcon(int cx, int cy, const String& code) {
  String k = code.substring(0, 2);
  if      (k == "01") drawSun(cx, cy, 15);
  else if (k == "02") { drawSun(cx - 9, cy - 9, 10); drawCloud(cx + 5, cy + 7, 28); }
  else if (k == "03" || k == "04") drawCloud(cx, cy, 32);
  else if (k == "09" || k == "10") { drawCloud(cx, cy - 7, 28); drawRain(cx, cy + 16); }
  else if (k == "11") { drawCloud(cx, cy - 7, 28); drawBolt(cx, cy + 13); }
  else if (k == "13") { drawCloud(cx, cy - 7, 28); drawSnow(cx, cy + 14); }
  else if (k == "50") drawMist(cx, cy);
  else drawCloud(cx, cy, 30);
}
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
void loop() {
  ArduinoOTA.handle();   // service Wi-Fi firmware updates

  // Execute whatever the web handlers queued (blocking SPI/TLS work lives here).
  Pending job = pending;
  if (job != P_NONE) {
    pending = P_NONE;
    if      (job == P_TEXT)    drawText(currentText);
    else if (job == P_WEATHER) { fetchAndDrawWeather(); lastWxFetch = millis(); }
    else if (job == P_STATION) drawStation();
    else if (job == P_CLOCK)   drawClock();
    else if (job == P_CLEAR)   clearDisplay();
    else if (job == P_CYCLE)   cycleScreen();
    else if (job == P_DEEP)    { deepRefresh(); redrawCurrent(); lastDeep = millis(); }
  }

  // Battery sample (cheap; just gates whether the overlay shows).
  if (millis() - lastBatt > BATT_MS) { readBattery(); lastBatt = millis(); }

  // Physical button (active-low, debounced) -> next screen.
  int reading = digitalRead(PIN_BTN);
  if (reading != btnReading) { btnReading = reading; btnTime = millis(); }
  if (millis() - btnTime > 40 && reading != btnStable) {
    btnStable = reading;
    if (btnStable == LOW) cycleScreen();
  }

  // Page the text screen 4 lines at a time (clean full refresh per page) until
  // the last page, then hold.
  if (mode == MODE_TEXT) {
    uint8_t total = lineCount(currentText);
    uint8_t pages = (total + TEXT_VISIBLE_LINES - 1) / TEXT_VISIBLE_LINES;
    if (pages > 1) {
      uint8_t maxPage = pages - 1;
      if (textScroll < maxPage && millis() - lastScroll > PAGE_MS) {
        textScroll++;
        lastScroll = millis();
        drawText(currentText);                       // full refresh of the next page
        if (textScroll >= maxPage) scrollDoneAt = millis();
      }
    }
  }

  // Auto-cycle: advance on a timer. On a scrolling text screen, don't move on
  // until SCROLL_HOLD_MS (5 s) after the last line has scrolled into view.
  if (autoCycle) {
    bool ready;
    if (mode == MODE_TEXT && lineCount(currentText) > TEXT_VISIBLE_LINES)
      ready = (scrollDoneAt != 0) && (millis() - scrollDoneAt > SCROLL_HOLD_MS);
    else if (mode == MODE_TEXT)
      ready = (millis() - lastCycle > TEXT_DWELL_MS);     // short note: fixed dwell
    else
      ready = (millis() - lastCycle > CYCLE_MS);
    if (ready) cycleScreen();
  }

  // Keep weather fresh while it's the active mode.
  if (mode == MODE_WEATHER && millis() - lastWxFetch > WX_REFRESH_MS) {
    fetchAndDrawWeather();
    lastWxFetch = millis();
  }

  // Tick the clock once per minute while it's showing.
  if (mode == MODE_CLOCK) {
    struct tm ti;
    if (getLocalTime(&ti, 0) && ti.tm_min != lastClockMin) drawClock();
  }

  // Station mode with no data yet: keep the "waiting" screen visibly counting,
  // then fall back so the panel never looks hung.
  if (mode == MODE_STATION && !st.received) {
    if (millis() - stationModeSince > STATION_WAIT_MS) {
      if (weatherZip.length()) { mode = MODE_WEATHER; fetchAndDrawWeather(); lastWxFetch = millis(); }
      else                     { mode = MODE_TEXT;    drawText(currentText); }
    } else if (millis() - lastWaitDraw > WAIT_REDRAW_MS) {
      drawStation();          // redraw waiting screen with updated counter
      lastWaitDraw = millis();
    }
  }

  // Periodically scrub e-paper ghosting, then restore the current view.
  if (millis() - lastDeep > DEEP_REFRESH_MS) {
    deepRefresh();
    redrawCurrent();
    lastDeep = millis();
  }

  delay(20);
}

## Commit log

2026-06-24 Initial commit: ESP32 e-paper web display
    Multi-line text + clear-screen over an async web server, driving a
    2.13" SSD1680 panel via GxEPD2. Includes PlatformIO config and a
    project journal for cross-machine work.
2026-06-24 Add persistent IP label on panel; refresh README setup
    - Render device IP in the built-in 6x8 font at bottom-left on every
    draw (drawText + clearDisplay), so it's always visible.
    - Move boot draw to after Wi-Fi connect so the first render has the IP.
    - README: document secrets.h for credentials and both PlatformIO and
    Arduino IDE flashing paths.
    - Journal: log today's work.
2026-06-25 Add weather mode + Three Oak Woods themed control page
    - New display mode switch: Text card + Weather card on the page. The
    Weather card asks for a US ZIP (this is how you switch to weather).
    - Weather from wttr.in (no API key): one-line format parsed without
    JSON, HTTPS via WiFiClientSecure, ASCII-filtered for the panel font.
    Shows ZIP/temp/condition; auto-refreshes every 15 min.
    - Web handlers now queue a Pending action that loop() executes, keeping
    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
2026-06-25 Upgrade weather: OpenWeatherMap + drawn icons and fancy layout
    - Switch weather source from wttr.in to OpenWeatherMap (key in
    secrets.h as OWM_API_KEY). Parse JSON with ArduinoJson. Now resolves
    the real city name plus feels-like, humidity, wind, and icon code.
    - Fancy panel: city header + rule, a drawn 1-bit weather icon, big
    temperature (24pt) with a hand-drawn degree ring, condition text, and
    a feels/humidity/wind detail line. IP stays bottom-left.
    - Weather icons are GFX primitives keyed off the OWM icon code (no
    bitmaps). Add FreeSansBold9pt/24pt fonts.
    - platformio.ini: add ArduinoJson, use huge_app partition for headroom.
    - README + JOURNAL updated.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
    [esp32-epaper-web.ino]
2026-06-25 Add local Ambient Weather station mode (console push)
    - New /data/report/ endpoint ingests the console's "Customized"
    AmbientWeather-protocol upload (tempf, humidity, wind, gust, winddir,
    dailyrain, baromrel) and replies 200 OK. Fully local, no API key.
    - New Backyard Station display mode: big outdoor temp + humidity / wind
    (with compass) / gust / rain / pressure; redraws on each push.
    - Page gains a Station card + live summary; /station endpoint.
    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
2026-06-25 IP in both bottom corners; fix weather detail overflow
    - drawIpLabel() now renders the IP in both bottom corners (lower-left
    and right-aligned lower-right).
    - Tighten weather detail line so the wind value no longer runs off the
    right edge (dropped "F" after feels, reduced spacing).
    [esp32-epaper-web.ino]
2026-06-25 Add deep-refresh de-ghosting and station waiting timeout
    - deepRefresh(): flash black/white to scrub e-paper ghosting, then
    redraw current view. Runs every 6h and via a Clean button (/refresh).
    - Station "waiting for push" now shows a live counter, redraws every
    20s, and falls back to weather (or text) after 90s so it never looks
    hung when the console isn't pushing yet.
2026-06-25 Fix station push parsing (accept POST body) + add /debug
    - /data/report/ now reads each field from query string, POST form
    params, or the raw urlencoded body. The console likely POSTs its
    readings; the old GET-only handler parsed nothing.
    - Capture raw POST body; add /debug endpoint (recent hits with method,
    source IP, parsed fields) and log 404s via onNotFound, so the real
    console's requests are visible without a serial monitor.
    [esp32-epaper-web.ino]
2026-06-25 Restore /clear route (regression)
    The /clear GET handler was accidentally dropped when the station
    endpoints were added, so the Clear Screen button 404'd. Re-registered
    it; clearDisplay()/P_CLEAR were already intact.
2026-06-25 Add NTP clock as default view; persist last view to NVS
    - New Clock mode (default): NTP-synced date/time via configTzTime
    (Mountain Time, auto DST), big time + date, redrawn each minute.
    "Show Clock" button + /clock endpoint.
    - Persist mode + ZIP to NVS (Preferences) on every view change. On
    boot, a remembered ZIP restores the weather view; otherwise the
    clock. Verified across a real reboot.
    [esp32-epaper-web.ino]
2026-06-25 Add optional firmware static IP (no DHCP reservation on gateway)
    T-Mobile 5G Gateway has no DHCP reservation option, so the station
    push needs a fixed target. WiFi.config() guarded by USE_STATIC_IP in
    secrets.h; default 192.168.12.50, chosen below the DHCP pool (~.107)
    to avoid collisions. README documents the secrets.h block.
    [esp32-epaper-web.ino]
2026-06-25 Add 18650 battery power design + 3D-printed enclosure
    - enclosure/epaper-case.scad: parametric OpenSCAD case (shell + front
    plate) with ESP32 standoffs, 18650 cradle, charger pocket, USB slot,
    switch hole, corner screws. Rendered STLs included (manifold-clean,
    no supports).
    - enclosure/README.md: load-sharing charger power design (PowerBoost
    1000C / IP5306), BOM, wiring, runtime estimate, print + assembly.
    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
    [epaper-case-front.stl, epaper-case-shell.stl, epaper-case.scad]
2026-06-25 Battery %, button cycling, auto-cycle, text scroll; enclosure v2
    Firmware:
    - Battery indicator (GPIO34 via 2:1 divider, auto-detected) top-right.
    - Physical button (GPIO27) cycles screens; /next and /cycle web routes.
    - Auto-cycle with longer dwell on the text screen when it has notes.
    - Text screen scrolls a 4-line window with a page indicator when >4 lines.
    Enclosure:
    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
    [epaper-case-shell.stl, epaper-case-stand.stl, epaper-case.scad]
2026-06-25 web-app branch: standalone SPA + /status.json API + CORS
    - Firmware: add /status.json (mode, ip, autoCycle, text, battery,
    weather, station) and a global Access-Control-Allow-Origin header so
    an off-device app can read the API. modeName() helper.
    - webapp/index.html: single-file Three Oak Woods themed SPA that polls
    /status.json and drives all device endpoints. No build step.
    - webapp/README.md + journal entry.
2026-06-25 Add weather + station views to the web app
    - /status.json: weather gains feels/humidity/wind/icon; station gains
    gust/rain/pressure/winddir.
    - SPA: Forecast card (icon + temp + condition + feels/humidity/wind)
    and Backyard station card (temp/humidity/wind+compass/gust/rain/baro).
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2026-06-25 Serve the web app from the device at /app + link on the page
    - Bundle webapp/index.html as webapp.h (raw literal) and serve it at
    /app; add an "Open the web app" link to the control page.
    - SPA defaults its host to location.origin when served over http, so
    the device-served copy targets itself (no CORS, no config).
    - webapp/README: device-served instructions + regen steps.
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2026-06-25 Persist message box text across reboots
    saveState() writes currentText to NVS; boot restores it and the text
    screen. Previously only mode/zip/cycle survived a power cycle.
    [esp32-epaper-web.ino]
2026-06-25 Enclosure: refined exterior + measured dims; re-add button/stand/keyholes
    Bring in the refined design (measured display dims; beveled rear,
    accent band, chamfered faceplate, recessed display surround, beveled
    window, softened countersinks). Re-add the top cycle-button hole, the
    stand part, and wall-mount keyholes that the refinement had dropped.
    Re-rendered shell/front/stand STLs + preview (all manifold-clean).
    [epaper-case-front.stl, epaper-case-shell.stl, epaper-case-stand.stl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]
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2026-06-25 Text scroll: partial refresh (no de-ghost), smaller font, scroll-then-hold
    - drawText(msg, partial): scroll steps use setPartialWindow (no black
    flash) and skip hibernate; full refresh only on initial/mode-entry.
    - Message font 12pt -> 9pt (FreeSansBold9pt7b); LINE_HEIGHT 22 -> 18.
    - Non-wrapping scroll that stops at the last line; auto-cycle waits 5s
    after the last line scrolls in before advancing.
    [esp32-epaper-web.ino]
2026-06-25 Scroll: fix partial-refresh overlay; keep message font at 12pt
    - Don't hibernate during a scrolling text sequence — hibernate wiped
    the controller's previous frame, so partial steps overlaid old text.
    Staying powered lets each partial cleanly clear the prior screen.
    - Revert message font 9pt -> 12pt (9pt too small).
    [esp32-epaper-web.ino]
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2026-06-27 Journal: board reflashed as sprinkler by mistake; recovery prepped
    The deployed e-paper board (MAC 08:b6:1f:f0:01:64, was static .50) was
    mistaken for a spare and reflashed with the sprinkler firmware. Re-cloned
    the repo, recreated secrets.h, verified the build. Documents how to
    restore once a board + the Inland panel are available.
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2026-06-29 Add OTA (ArduinoOTA) updates + fix OWM key on deployed board
    - ArduinoOTA: hostname "epaper" :3232, handle() in loop, optional
    OTA_PASSWORD. New env esp32dev_ota (espota) for Wi-Fi flashing.
    - Switch partitions huge_app -> min_spiffs (two ~1.9MB OTA app slots);
    OTA needs two app partitions. Requires one USB flash to apply.
    - OWM 401 was a stale key in the deployed board's flash, not a bad key
    (key tests valid). Re-flash from secrets.h restores weather.
    - platformio.ini upload_port COM3 -> COM7.
    - Verified: USB flash of the new scheme, then a full over-Wi-Fi OTA
    (Result OK), device rebooted clean, weather valid.
    [esp32-epaper-web.ino]
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2026-07-01 Journal: COM9 board now IS .50 (replaces old deployed unit)
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2026-07-15 Port to ESP8266 (ESP-12E) + add Wi-Fi AP-mode recovery on both platforms
    AP-mode fallback (shared code, ESP32 + ESP8266):
    - connectWiFi() replaces the infinite connect loop with a bounded
    timeout. Boot tries stored creds (from a prior /wifisave) then the
    compiled secrets.h defaults; if both fail, starts an open recovery
    AP (EPaper-Setup-<mac>, 192.168.4.1) and draws the AP name + IP
    directly on the panel. New always-on Wi-Fi card on the control page
    posts to /wifisave, which persists creds and reboots.
    - Verified live: forced a failure with a bogus SSID, confirmed the
    timeout, AP start, panel draw, and OTA-in-AP-mode via serial: then
    restored the real network.
    ESP8266 (ESP-12E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
    [esp32-epaper-web.ino]
2026-07-17 ESP8266 board takes over .50 (ESP32 unit retired)
    User retired the ESP32 unit at .50 and designated the ESP8266/ESP-12E
    board (was DHCP .206) as its replacement. Widen the static-IP guard
    from ESP32-only to both platforms (ESP8266WiFi's WiFi object has a
    compatible .config()/.mode() API, so no other code changes needed).
    Also defuse a real footgun: esp32dev_ota's upload_port still pointed
    at .50, which is now the ESP8266 board — OTA has no architecture
    check, so an ESP32 binary pushed there could brick it. Replaced with
    a placeholder that forces a deliberate choice. esp12e_ota now targets
    .50 for future re-flashes.
    Verified via OTA flash (to .206, its address before the change) +
    reboot: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
    [esp32-epaper-web.ino]
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
